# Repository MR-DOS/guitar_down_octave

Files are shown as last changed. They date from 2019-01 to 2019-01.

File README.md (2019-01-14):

# guitar_down_octave
----
## Description
This is an analog guitar effect which works as octave-down effect. Contrary to all available analog octave-down effect (let me know if you find one!), it produces undistorted sinewave (when supplied with pure sinewave on input). There is no PLL, no oscillator

----
## Overview
So, you may want to know how it works. A long time ago, I was experimenting with octave-up effects. Recently, I thought that the principle of octave-up effects can be turned inside-out and a bit expanded to make an octave-down effect. The way most octave-up effects work (the good ones, simple ones only rectify the input waveform which is horrible) is as follows:

sin^2(x)=\frac{sin(2x)}{2}+\frac{1}{2}

If this function is inverted, you get:

\sqrt{\frac{sin(x)}{2}+\frac{1}{2}}=|sin(\frac{x}{2})|

However, this is not enough to turn sinewave into sinewave of half frequency. You need to remove the absolute value and this is where the analog mojo kicks in.
If you want more insight, look in the presentation where simulated waveforms can be found. If you are more curious, look into the schematics or simulation.

----
## Explanation of function
To sum it up, the circuit does the following: detect input amplitude and shift the input signal in such a way that the sinewave has its minimum at precisely 0 Vdc, find a square root of the shifted signal and normalize its amplitude so that input and output amplitudes are equal, then invert the signal at points where it gets closest to zero.

### 90deg phasing circuit
In order to detect extremes, you need to detect zero crossing of a derivation of the input signal. Initially, derivator was used, but it had several issues, most importantly its sensitivity was increasing with frequency whereas I needed quite the opposite, because the circuit needs to be most sensitive in the range of tens of Hz to several hundreds of Hz. The sensitivity also should decrease with rising frequency to make the phasing circuit more immune to harmonics (because signal from guitar is going to be flooded with harmonics). So a double integrator was used - one for the phasing circuit, one as DC servo. However, this circuit has a nasty peak at 32 Hz, so it had to be compensated with a Twin-T notch filter right on the input of the whole effect. It maintains proper 90deg +- 0.25deg phase from about 60 Hz and up. There is an additional RC T-network to accelerate convergence to 90deg at low frequencies, which allows for more gain in the integrator by using shorter time constant. It should work even with harmonic-rich signals, however the harmonics must be in phase (and not antiphase) with the fundamental frequency, otherwise an analysis of what will happen is nontrivial.

Schematics of the input circuit with the notch filter and the phasing circuit:
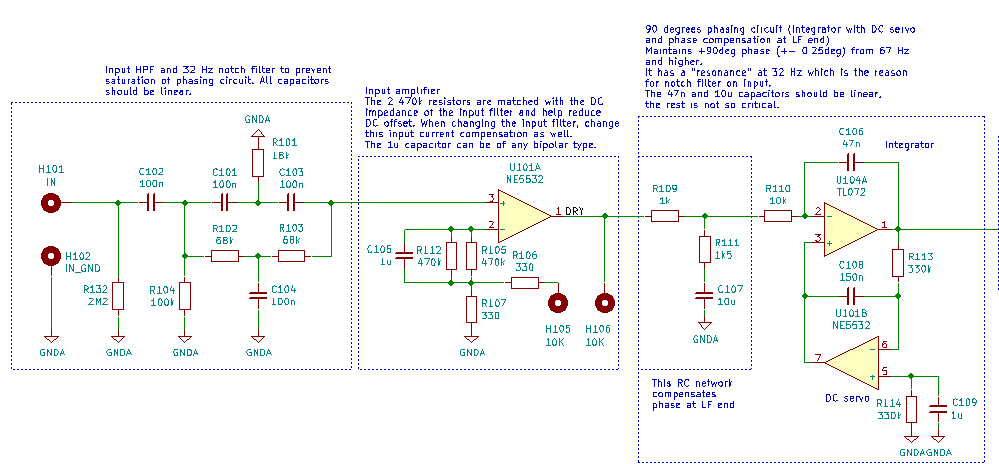
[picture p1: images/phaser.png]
Schematics of the input circuit with the notch filter and the phasing circuit


Green sine is the input waveform, blue is the 90deg shifted sine, red is output of the comparator:
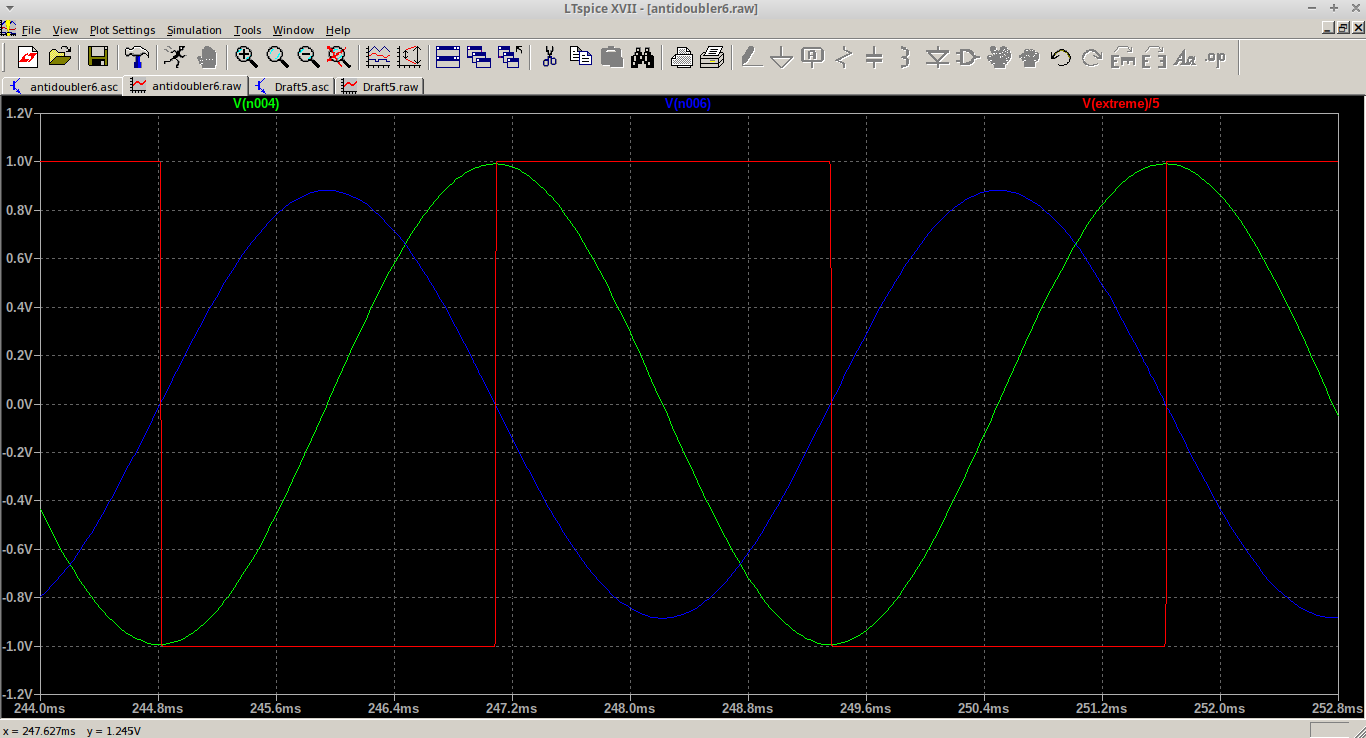
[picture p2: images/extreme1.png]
Green sine is the input waveform, blue is the 90deg shifted sine, red is output of the comparator


### Synchronous peak detector
There is a synchronous peak detector which uses 2 track-and-hold amplifiers (historical LF398). One of them tracks the input signal while the second one holds a peak value. Each time the input waveform goes through one of its extremes, their tasks are switched. At the same time, an analog switch selects the one which holds the peak value. This way, you get a fairly precise DC value representing the amplitude which is updated after each cycle of the sinewave. This was needed because regular peak detectors were too slow to react fast enough to dynamics of playing a guitar while being too fast to hold their value during the whole cycle of sinewave, so they would cause a lot of distortion and bad dynamics.
This part and the phasing circuit proved to be crucial for proper operation of the whole effect.

Green sine is the input waveform, blue and light blue waveforms are outputs of the track-and-hold amplifiers:
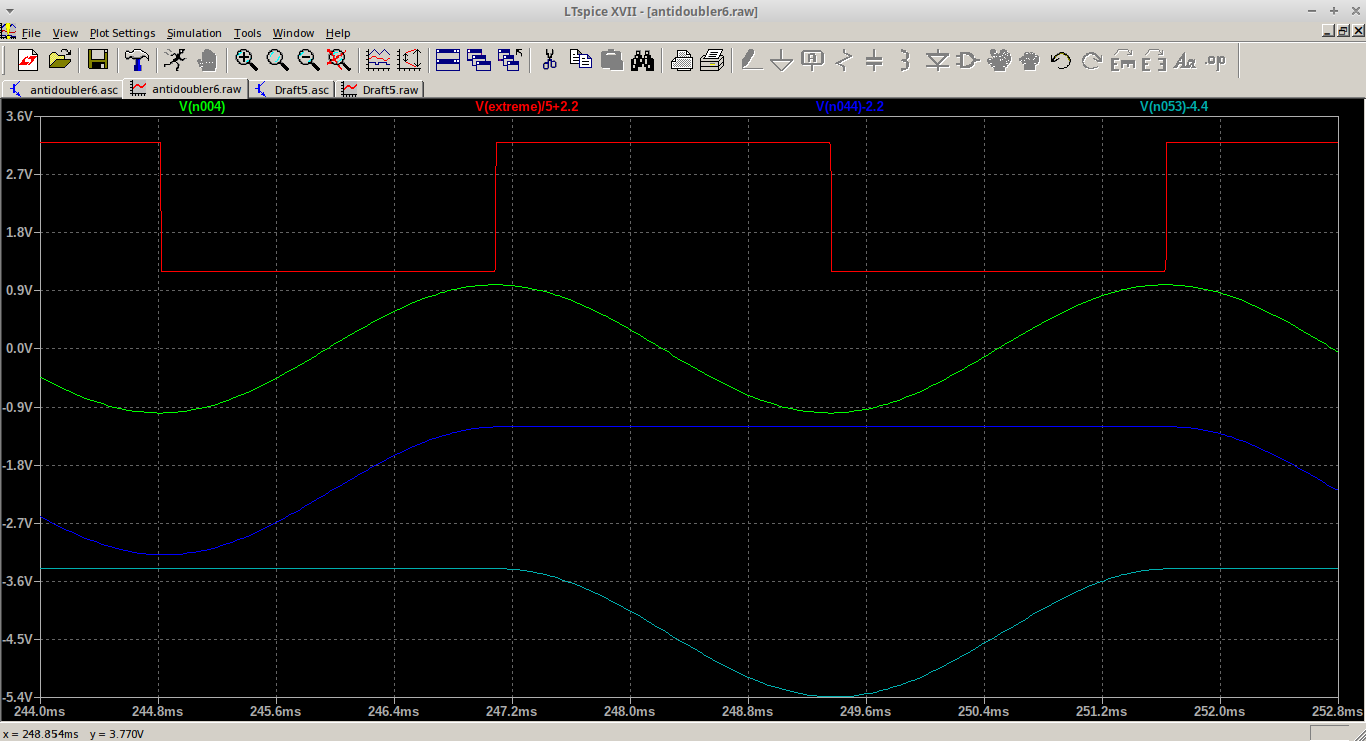
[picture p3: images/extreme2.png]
Green sine is the input waveform, blue and light blue waveforms are outputs of the track-and-hold amplifiers


### Square root finder
The square root finder is quite simple - it uses opamps and diodes to calculate the logarithm of the DC shifted signal, then divide by two (simple resistor divider) and exponentiate. This computes the square root even with proper sign. The only problem is very low speed of this circuit when crossing zero (which is why it never should cross the zero), because it momentarily goes open-loop and has to cross about 1.3 V rapidly.

Square-root-finder schematics:
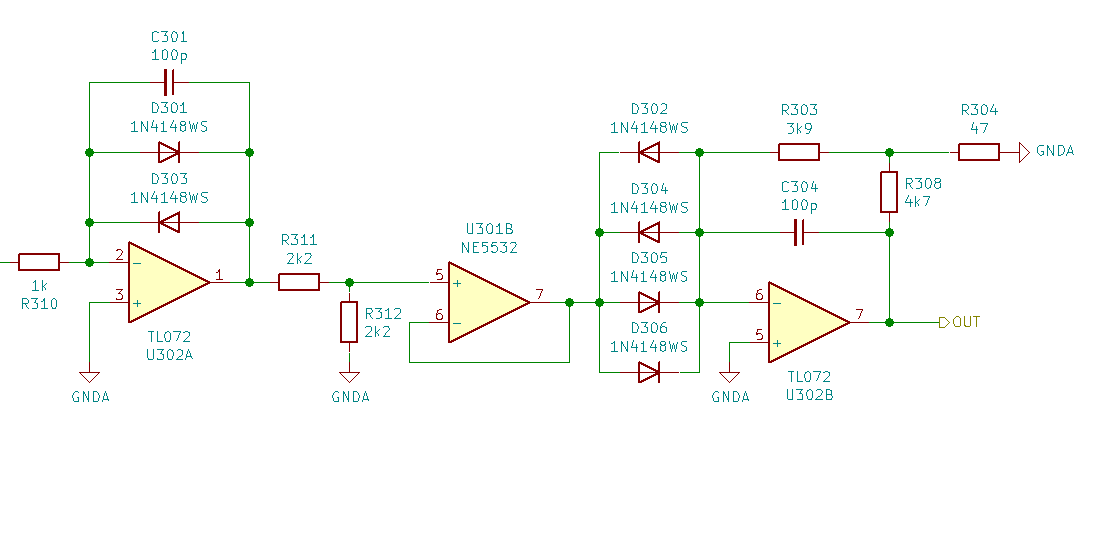
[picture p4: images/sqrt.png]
Square root-finder


Waveforms in the square-root-finder:
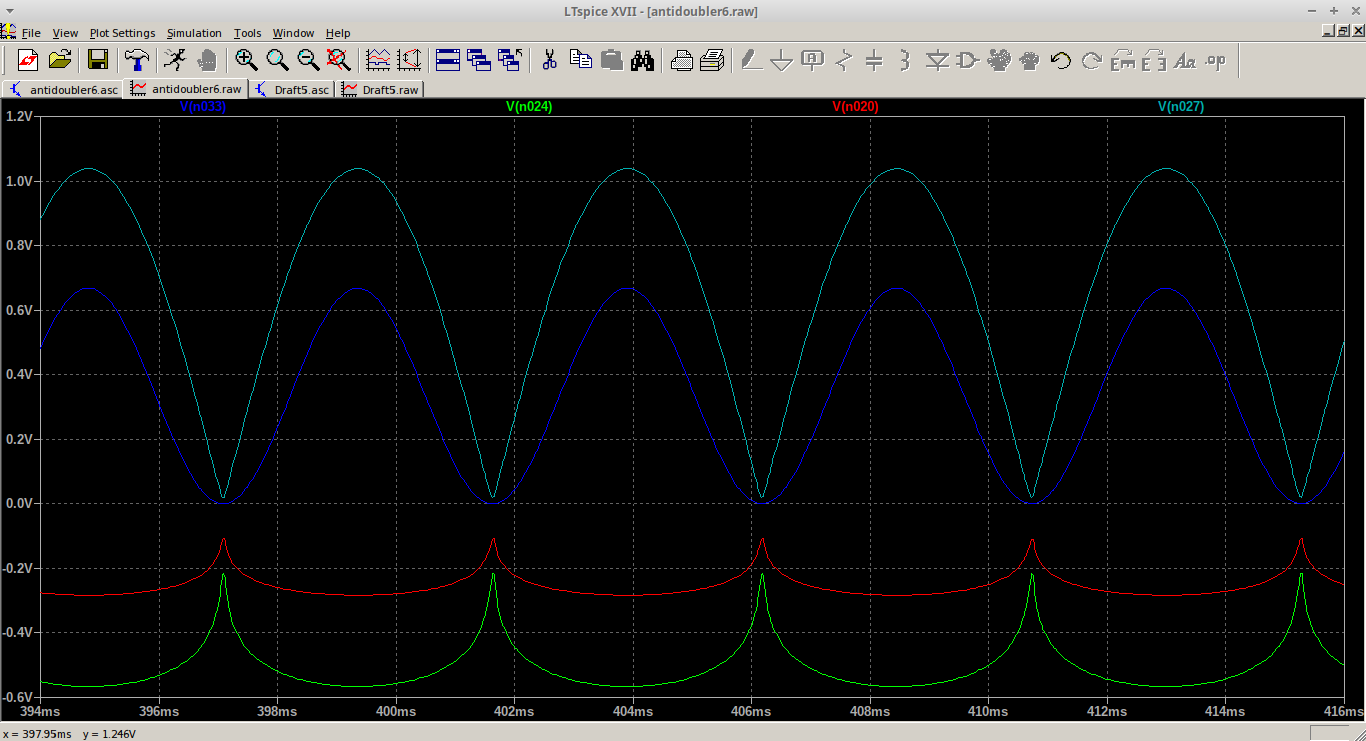
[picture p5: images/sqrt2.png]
Waveforms in the square-root-finder


### Synchronous inverter
To get rid of the absolute value, there is a synchronous inverter which inverts every second halfperiod of the sinewave. This uses the phasing circuit and 74HC74 to generate half frequency square wave which drives an analog switch which selects either positive or negative halfperiod of the sinewave. There is a simple RC filter to suppress crossover distortion.

Green and light blue line are the noninverted and inverted value, dark blue is the combined waveform:
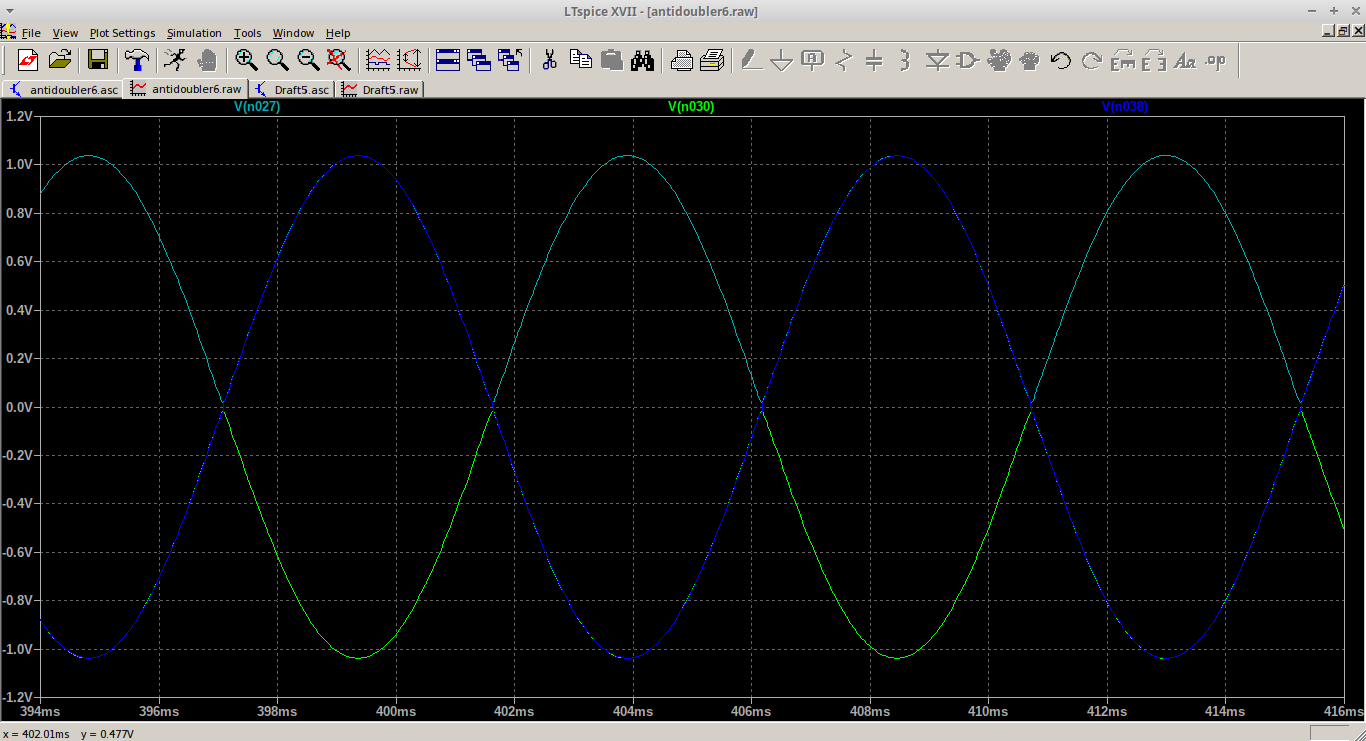
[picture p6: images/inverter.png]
Green and light blue line are the noninverted and inverted value, dark blue is the combined waveform


### AGC
To compensate for amplitude error due to the square-root, there is an AGC which uses Gilbert cells. Each square-root-finder is preceded by the Gilbert cell (there are 2), one has the sine wave as input, the second one gets the DC value of amplitude. The AGC tries to get the input and output amplitude the same.

Gilbert cell used as controlled amplifier:
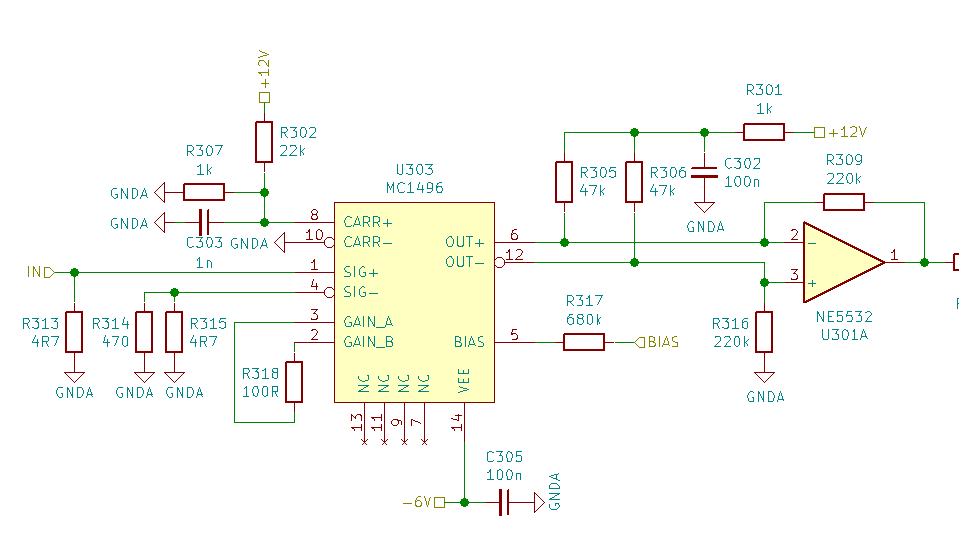
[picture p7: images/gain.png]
Gilbert cell used as controlled amplifier


Feedback used to compute the AGC value:
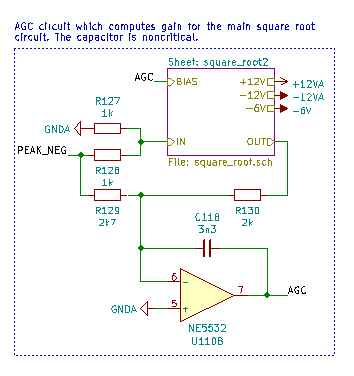
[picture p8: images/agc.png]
Feedback used to compute the AGC value


----
### Performance
Performance at 110 Hz, 1Vpk-pk:
The largest harmonic is the 3rd with -62.3 dBc, the THD is about 0.43% or 2.97% depending on how you define the THD. For a nonlinear guitar effect, it is probably satisfactory.

Image of FFT in simulation:
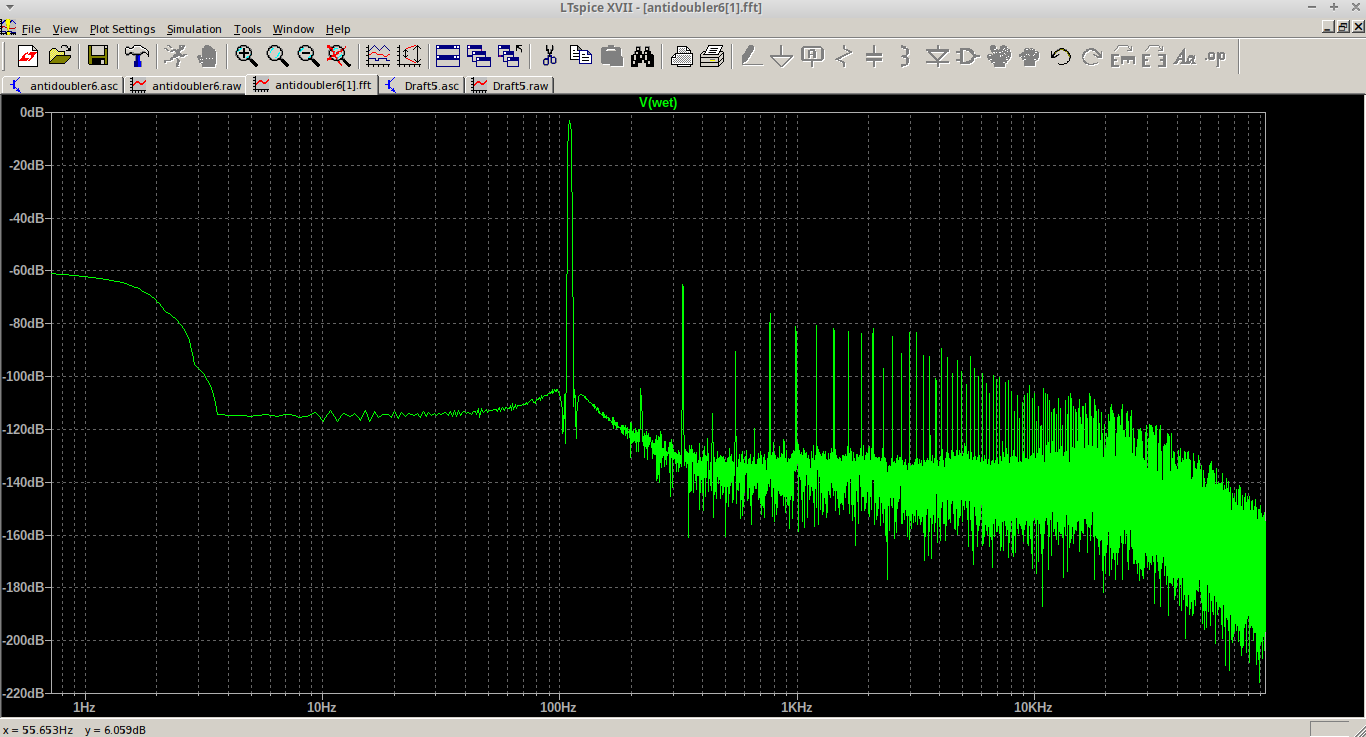
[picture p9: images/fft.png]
Image of FFT in simulation


----
## Images of the board
Top view:
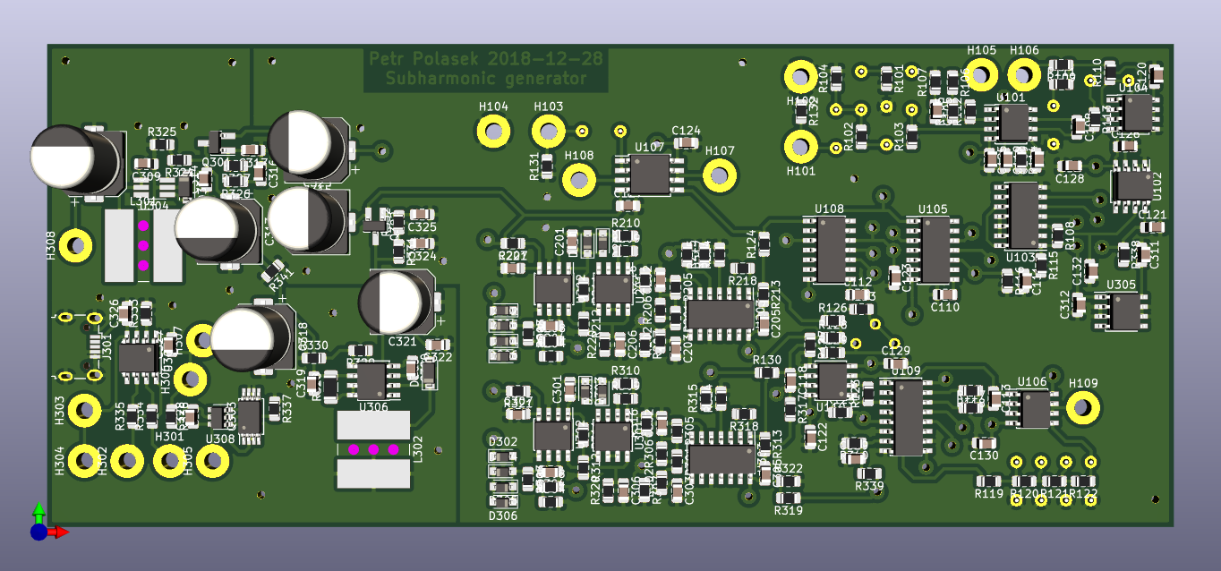
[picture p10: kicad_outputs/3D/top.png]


Bottom view:
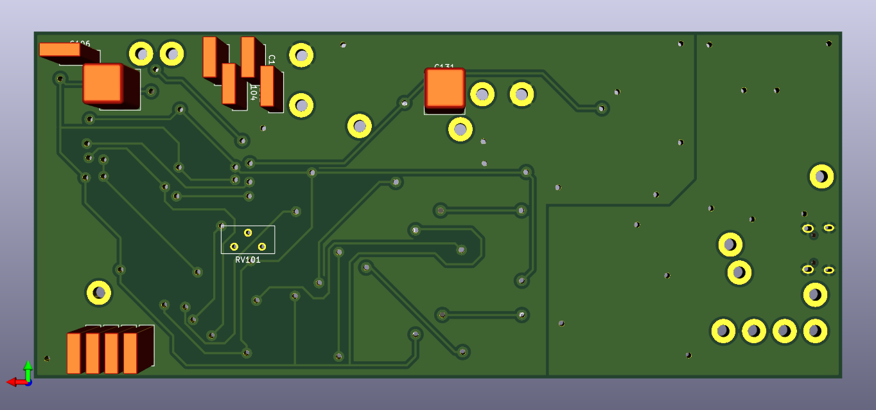
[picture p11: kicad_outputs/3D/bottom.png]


Top view, drilled and with vias in place:
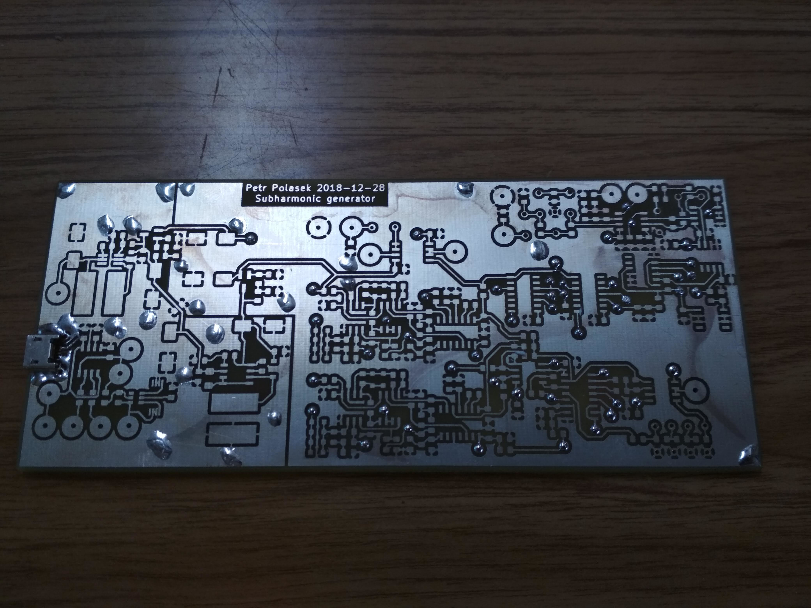
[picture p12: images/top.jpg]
Top view, drilled and with vias in place


Bottom view, drilled and with vias in place:
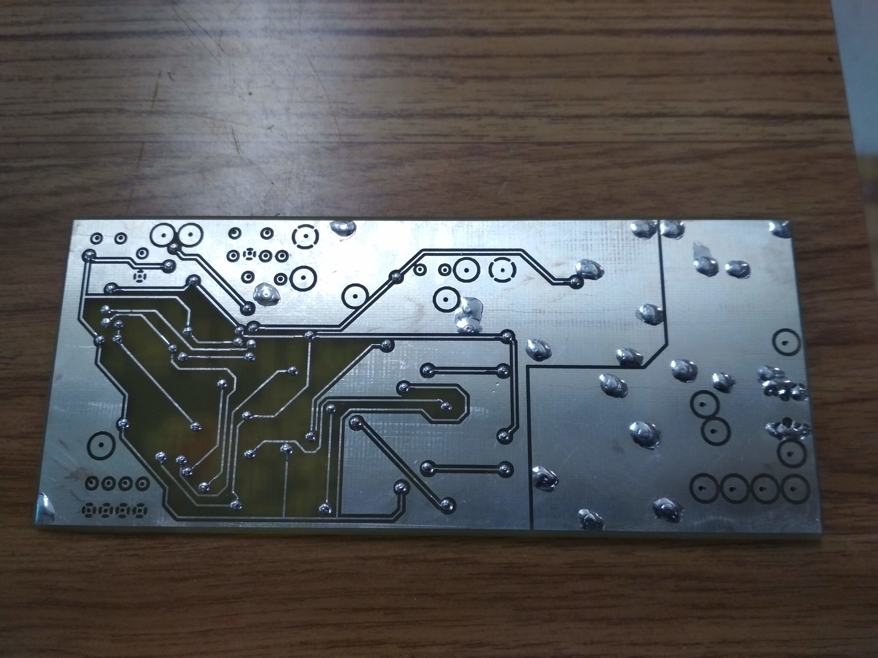
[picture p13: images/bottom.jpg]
Bottom view, drilled and with vias in place


Assembled board:
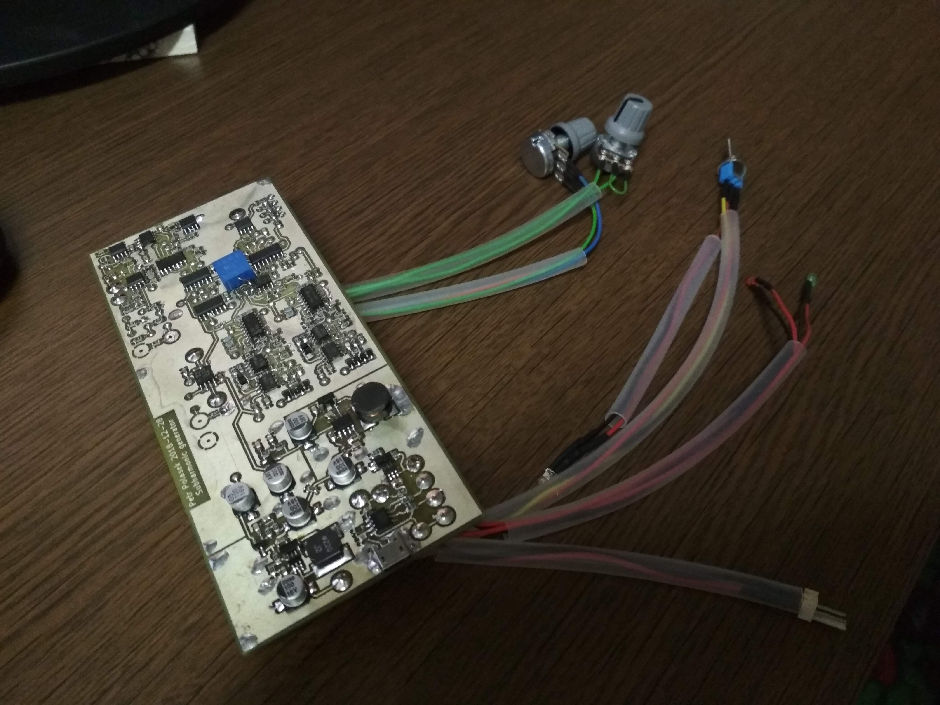
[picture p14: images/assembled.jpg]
Assembled board


----
## Known bugs
The -15 V switching power supply is a piece of shit. I will never EVER use MC34063, at least for negative power supply. The modern positive switching power supply is OK, it draws only tens of mA. The MC34063 draws one or two orders of magnitude larger current. Maybe it could be replaced by charge pump taken from the positive switching power supply - this means replacing the whole negative power supply by 2 diodes and 1 capacitor.

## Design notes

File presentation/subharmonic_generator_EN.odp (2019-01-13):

## Subharmonic generator B2M34IAS

Petr Polášek

3.1.2018

## 90° phasing circuit - schematic

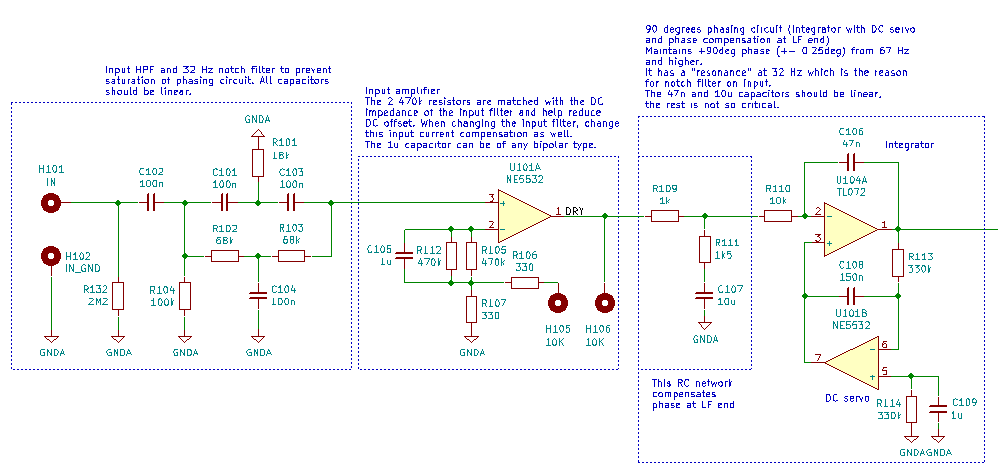
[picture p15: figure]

## 90° phasing circuit - schematic

## 90° phasing circuit - characteristics

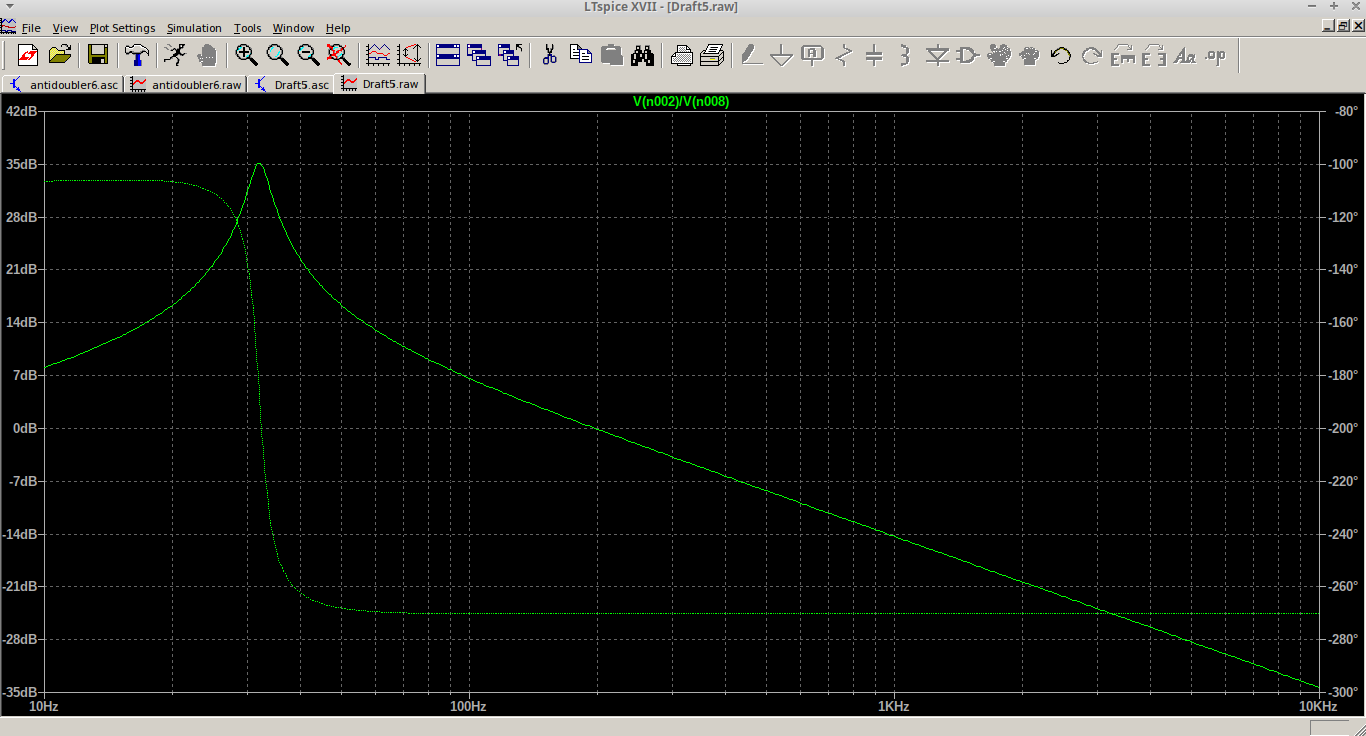
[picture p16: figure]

## 90° phasing circuit - schematic

## 90° phasing circuit – notch filter

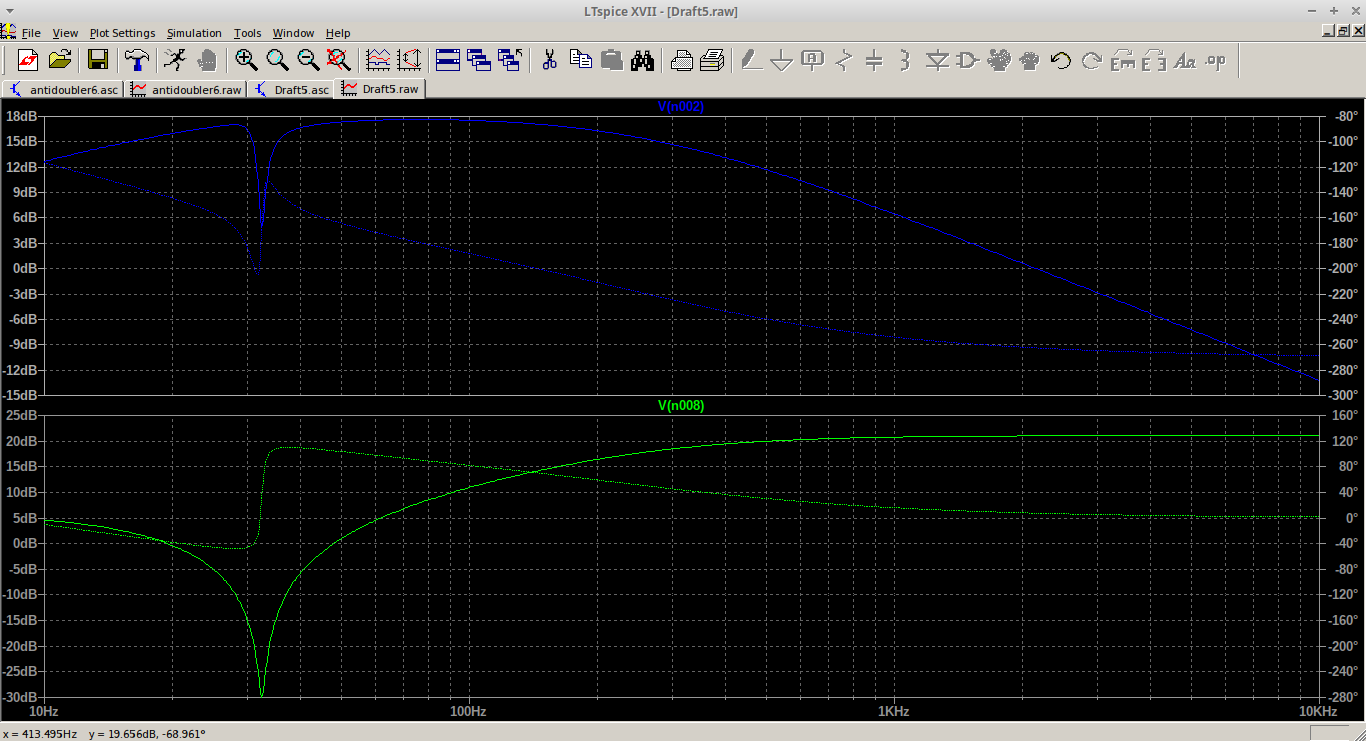
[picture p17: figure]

## 90° phasing circuit – phase accuracy

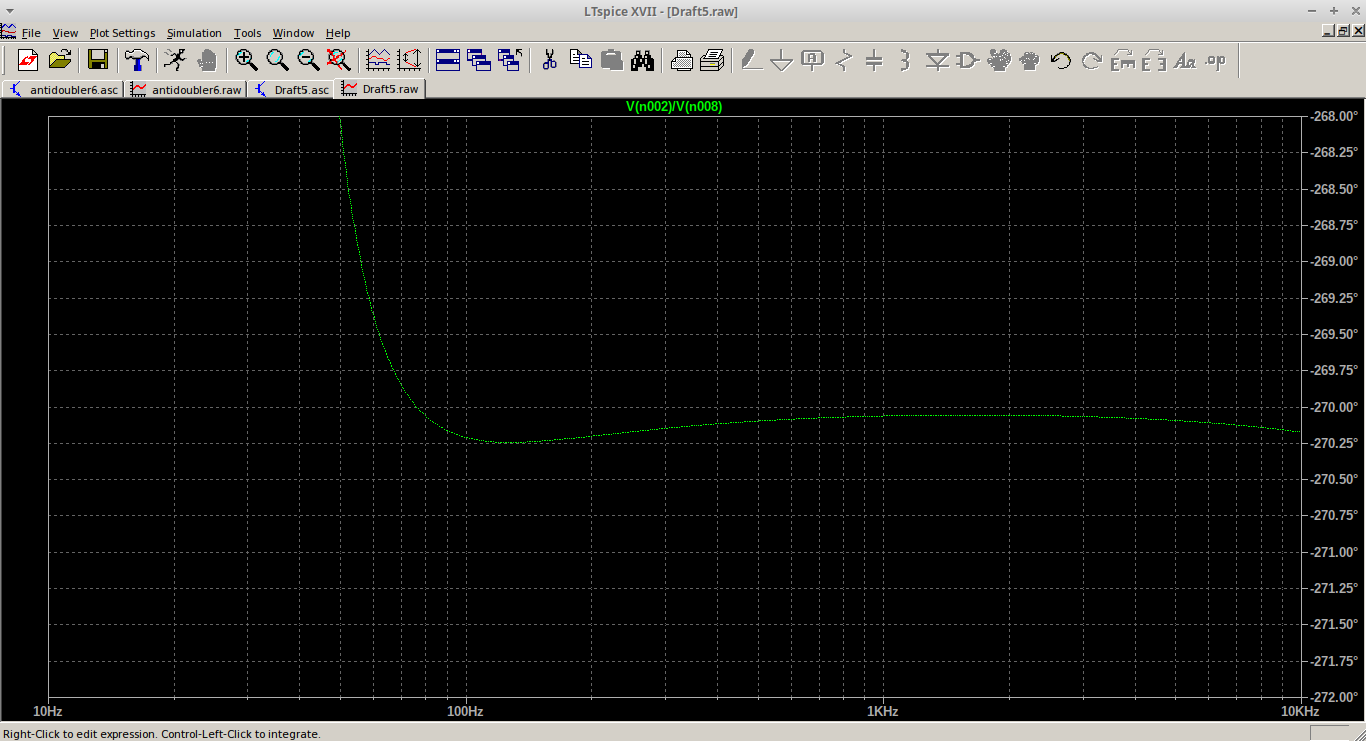
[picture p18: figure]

## Extreme detector - schematic

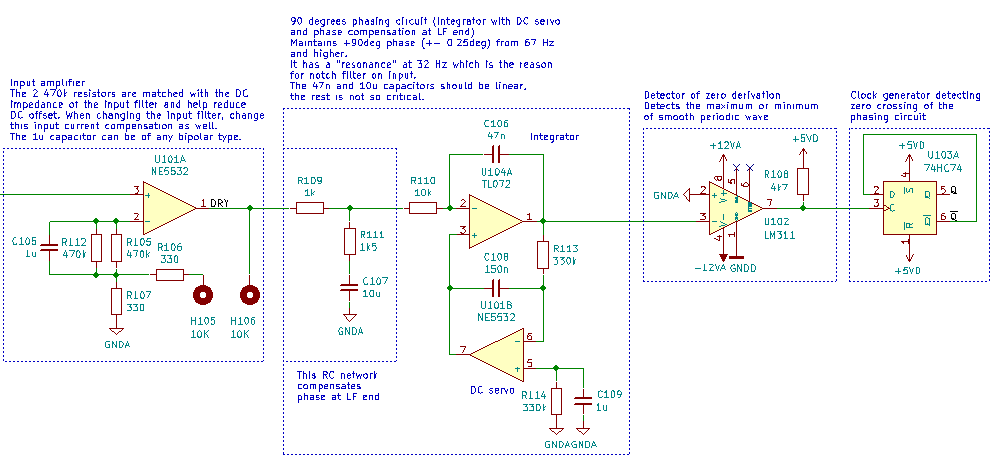
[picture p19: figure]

## Extreme detector - waveforms


## Synchronous extreme detectors

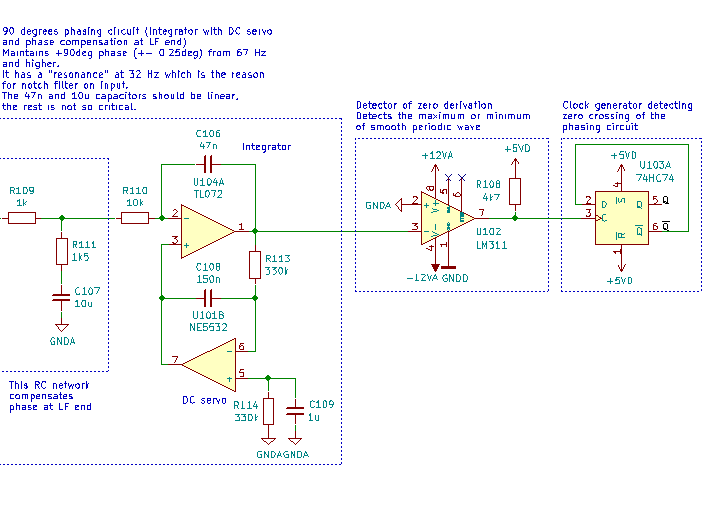
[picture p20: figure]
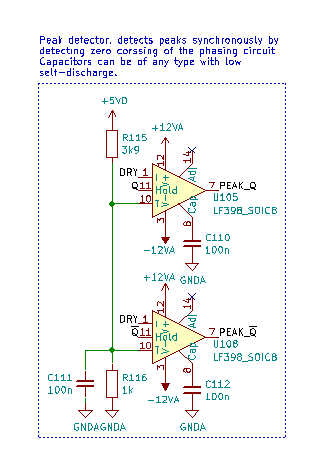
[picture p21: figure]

## Synchronous extreme detectors


## Synchronous extreme detectors

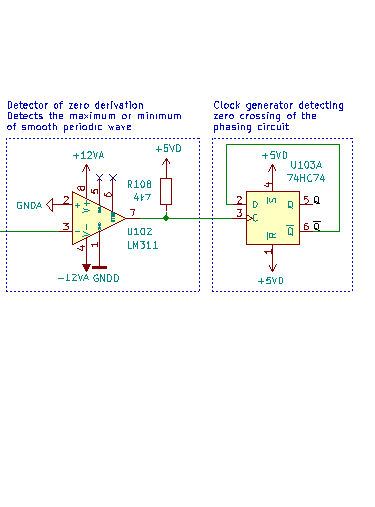
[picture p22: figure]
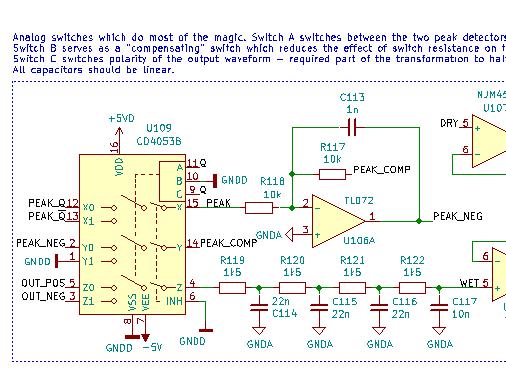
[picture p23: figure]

## Synchronous extreme detectors

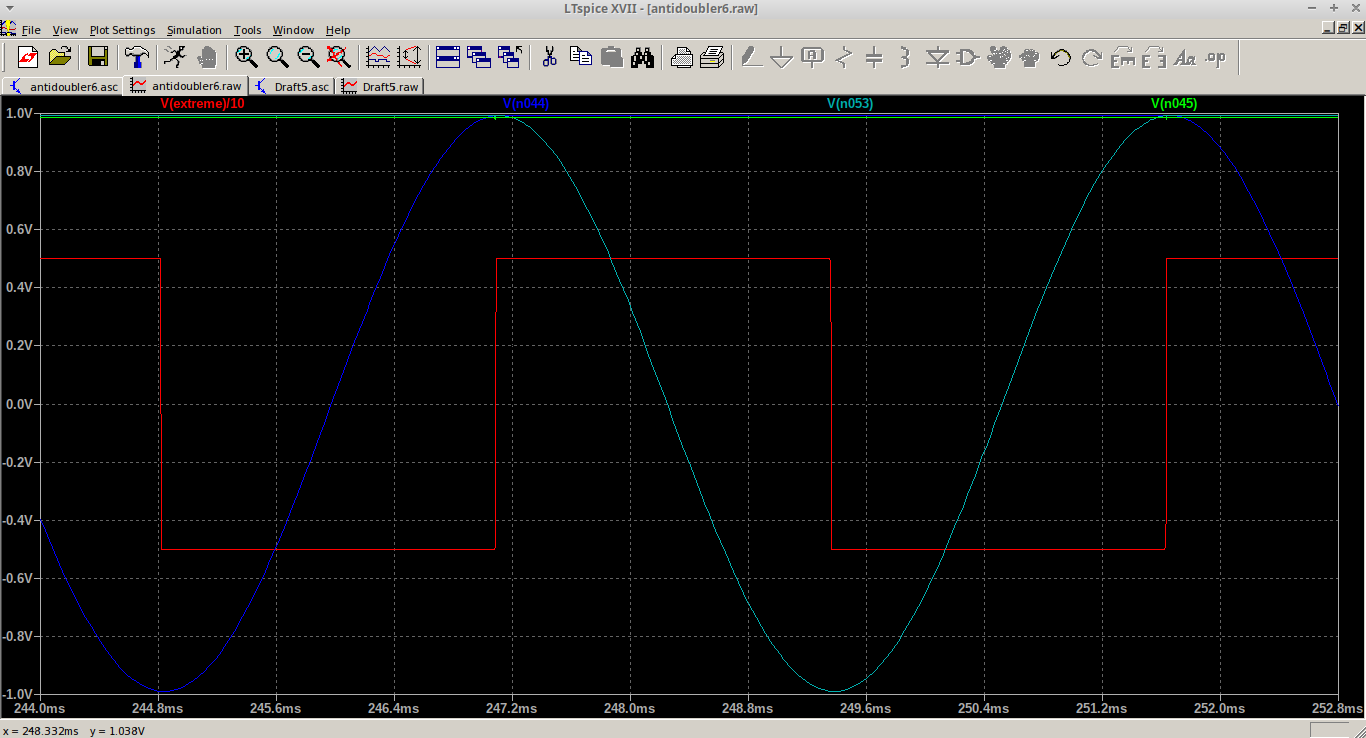
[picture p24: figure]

## Synchronous extreme detector accuracy

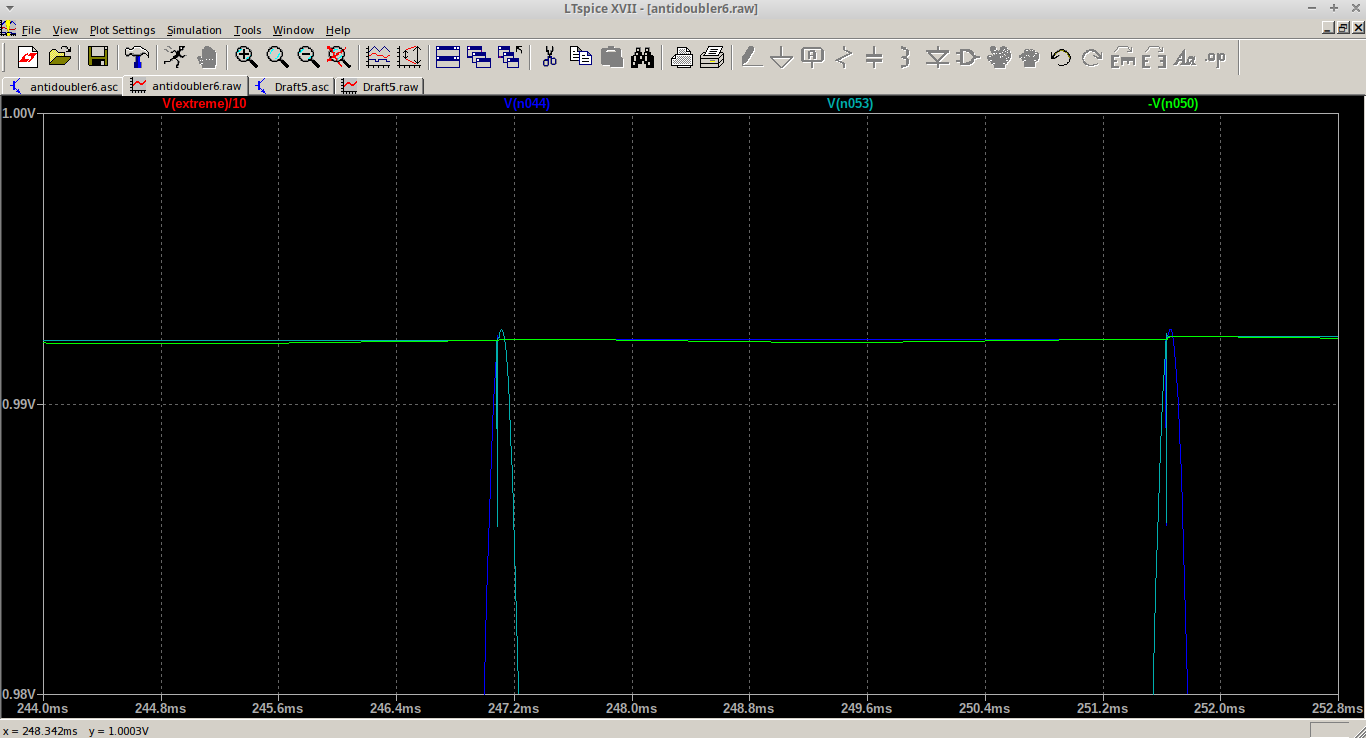
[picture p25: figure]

## Synchronous extreme detectors

0.35 mV @ 1V
0.03% error

## Square root finder - schematic

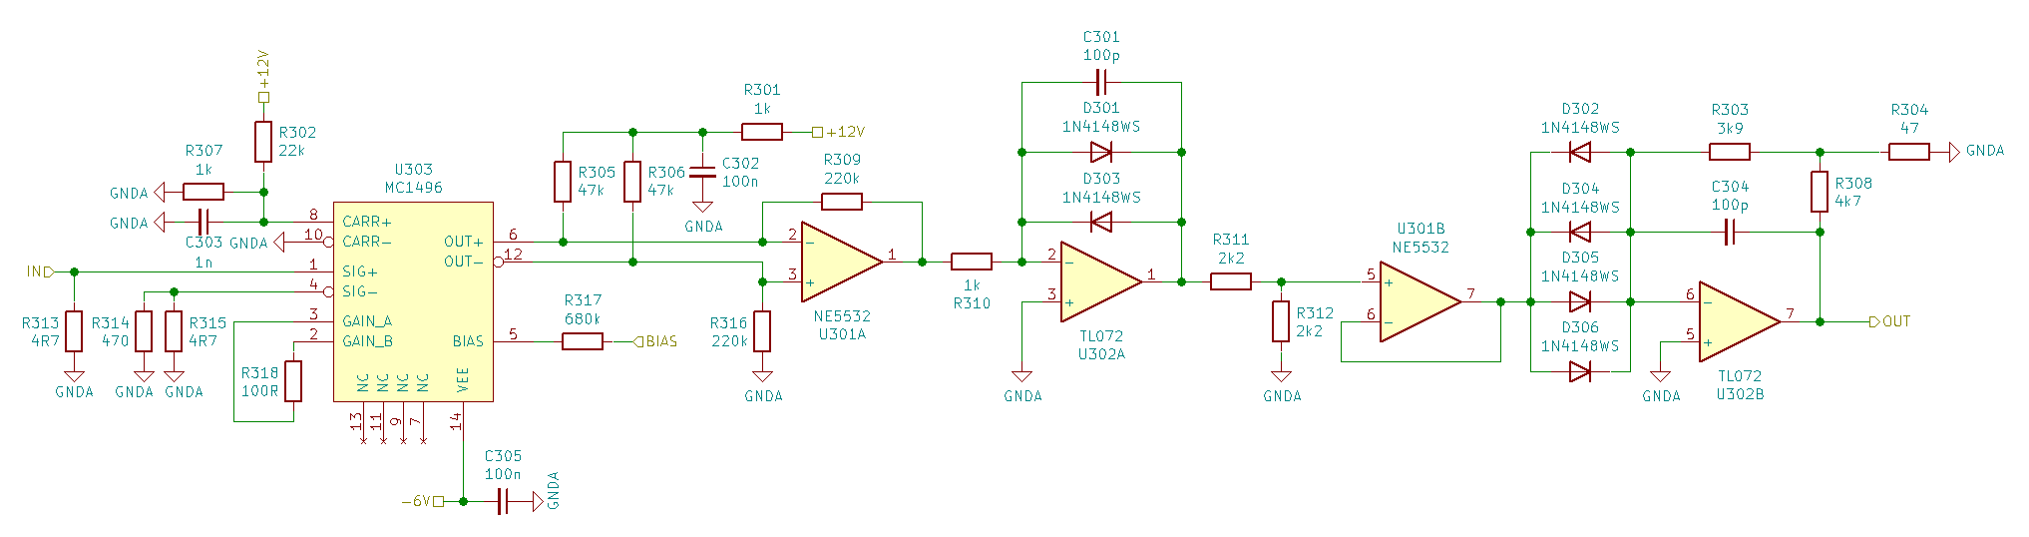
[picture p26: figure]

## Square root finder – gain control

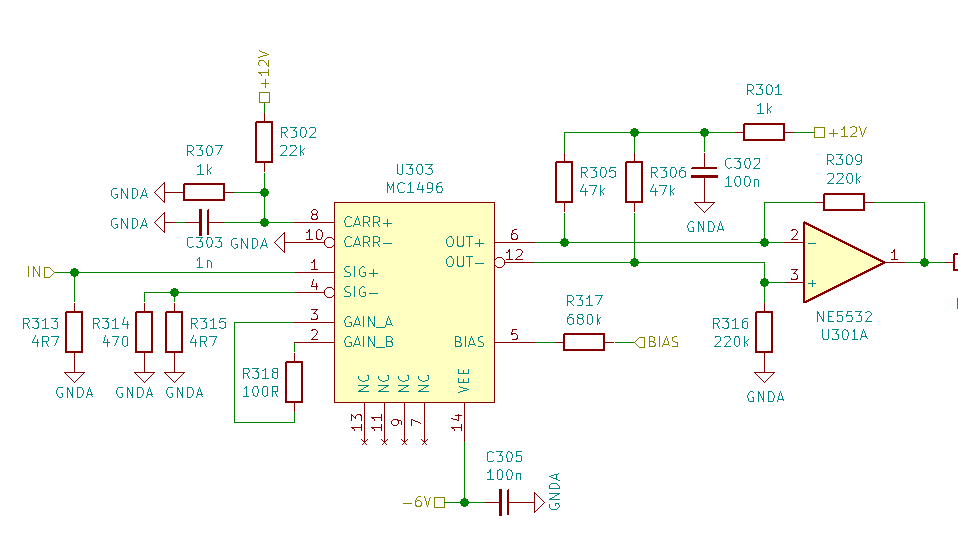
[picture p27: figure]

## Square root finder – square root cell

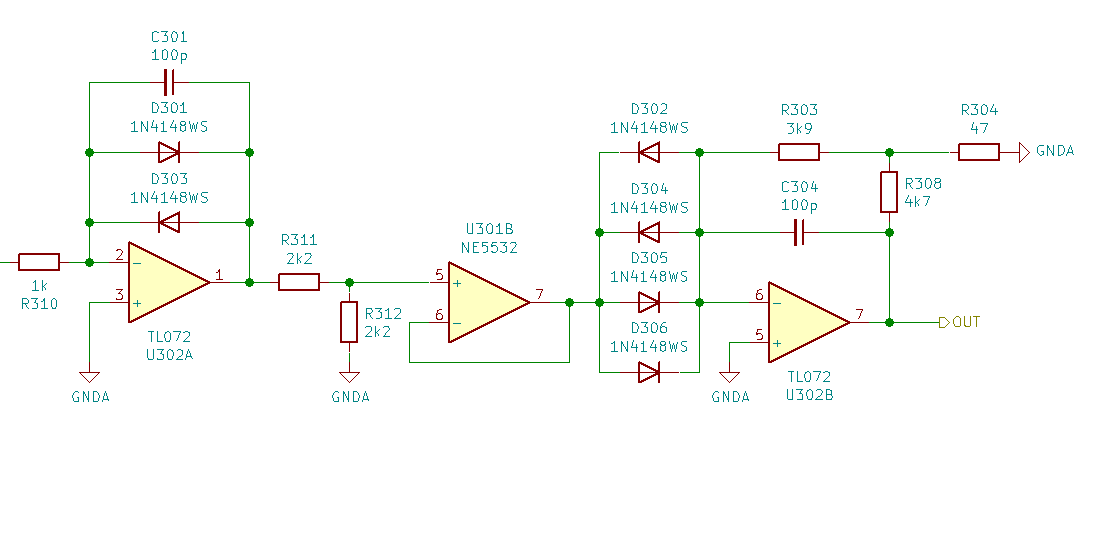
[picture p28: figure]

## Square root finder - waveforms


## Square root finder – AGC feedback

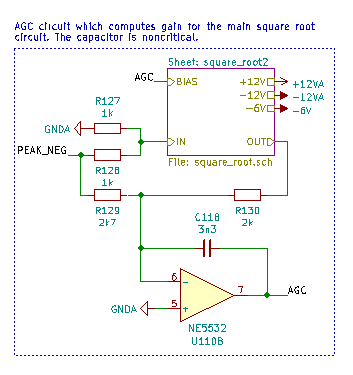
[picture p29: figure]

## Polarity inverter - schematics

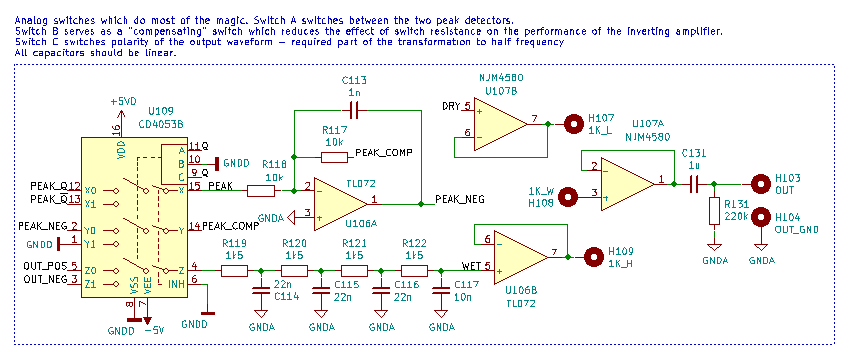
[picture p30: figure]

## Polarity inverter - waveforms


## Polarity inverter - schematics

## Polarity inverter – crossover distortion

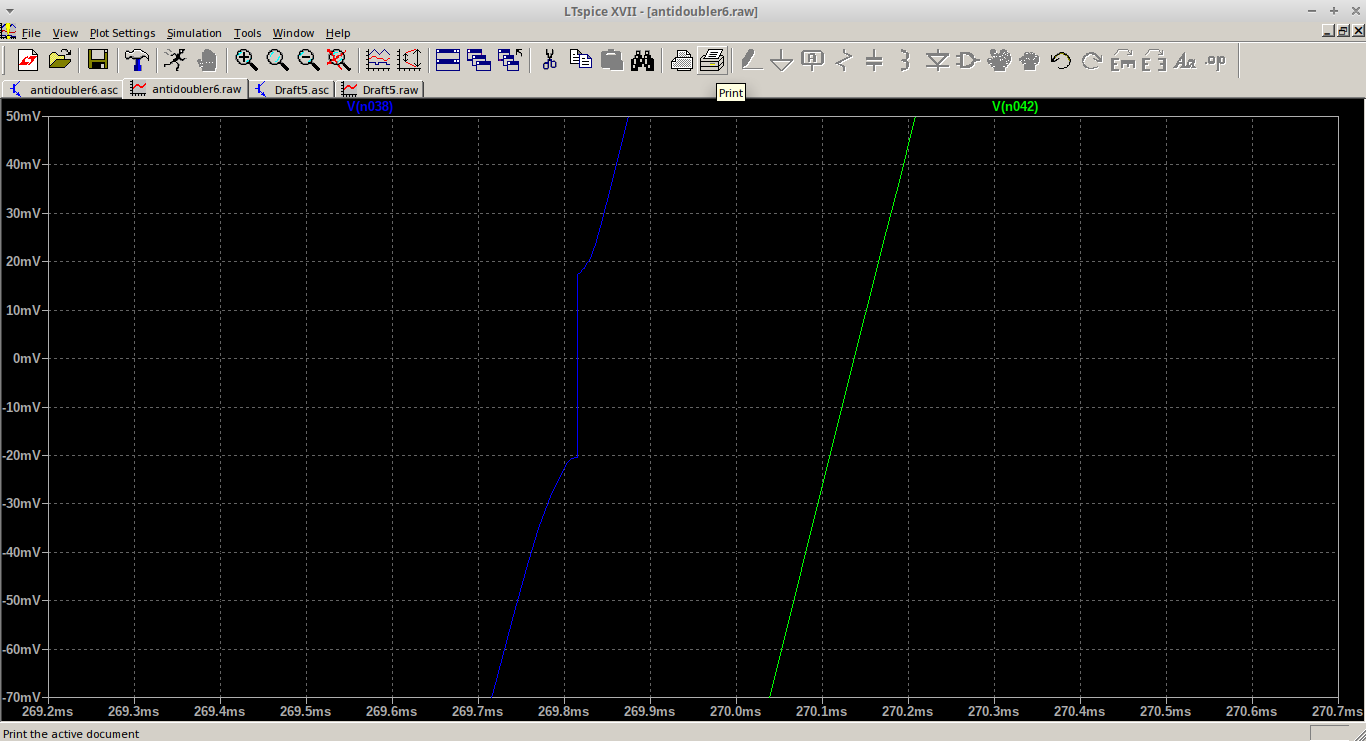
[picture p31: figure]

## Output signal FFT


## Output signal FFT - magnified

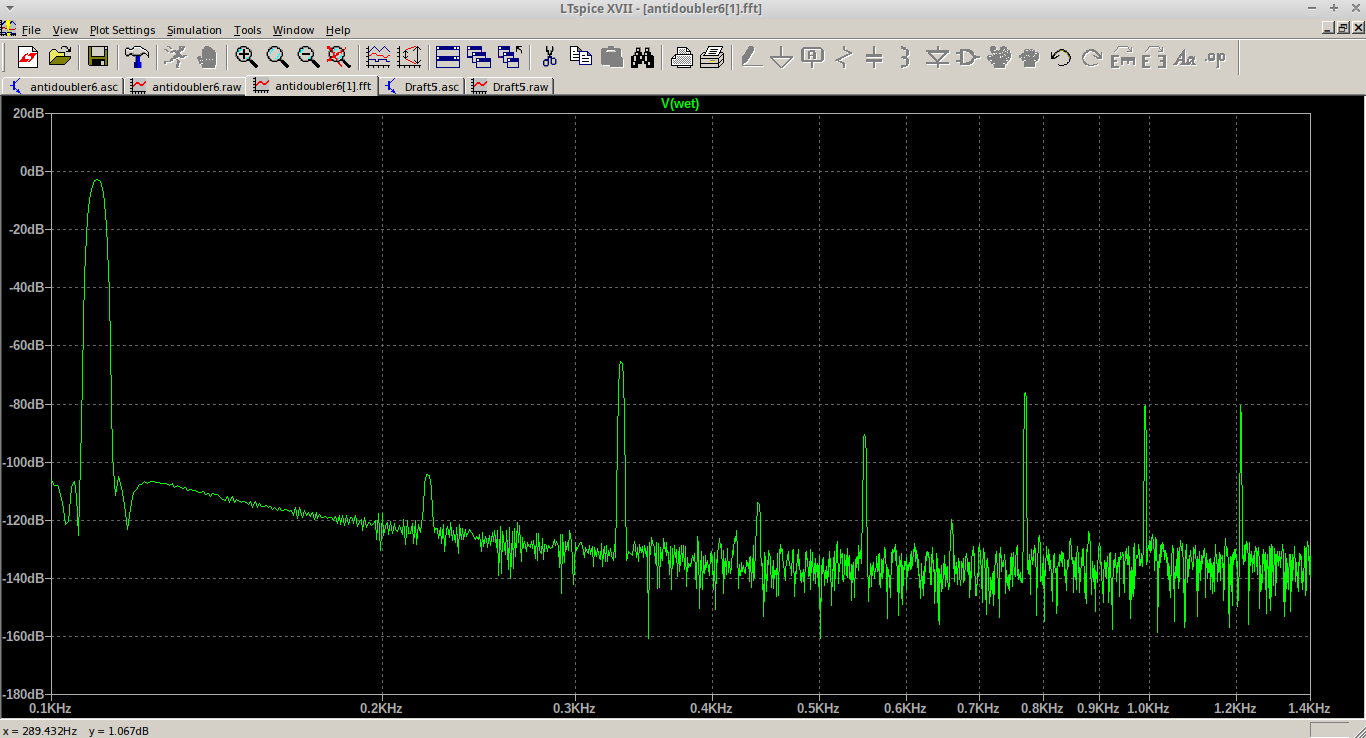
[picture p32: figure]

-62.3 dBc @ 3rd harmonic

THDR = 0.43 %

THDF = 2.97 %

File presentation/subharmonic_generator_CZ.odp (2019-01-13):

## Subharmonický generátor B2M34IAS

Petr Polášek

3.1.2018

## Fázovací 90° článek - zapojení


## Fázovací 90° článek - zapojení

## Fázovací 90° článek - přenos


## Fázovací 90° článek - zapojení

## Fázovací 90° článek – celkový přenos


## Fázovací 90° článek – přesnost fáze


## Detektor průchodu extrémem - zapojení


## Detektor průchodu extrémem - průběh


## Synchronní detektory maxima - zapojení


## Synchronní detektory maxima - průběhy


## Synchronní detektory maxima - zapojení


## Synchronní detektory maxima - průběhy


## Synchronní detektory maxima - průběhy


## Synchronní detektory maxima - průběhy

0.35 mV @ 1V
0.03% chyba

## Odmocňovací buňka - zapojení


## Odmocňovací buňka – řízení zisku


## Odmocňovací buňka - odmocňovačka


## Odmocňovací buňka - odmocňovačka


## Odmocňovací buňka – zpětná vazba


## Řízená inverze signálu - zapojení


## Řízená inverze signálu - průběhy


## Řízená inverze signálu - zapojení

## Řízená inverze signálu - offset


## FFT výstupního signálu


## FFT výstupního signálu - příblížení


-62.3 dBc

THDR = 0.43 %

THDF = 2.97 %

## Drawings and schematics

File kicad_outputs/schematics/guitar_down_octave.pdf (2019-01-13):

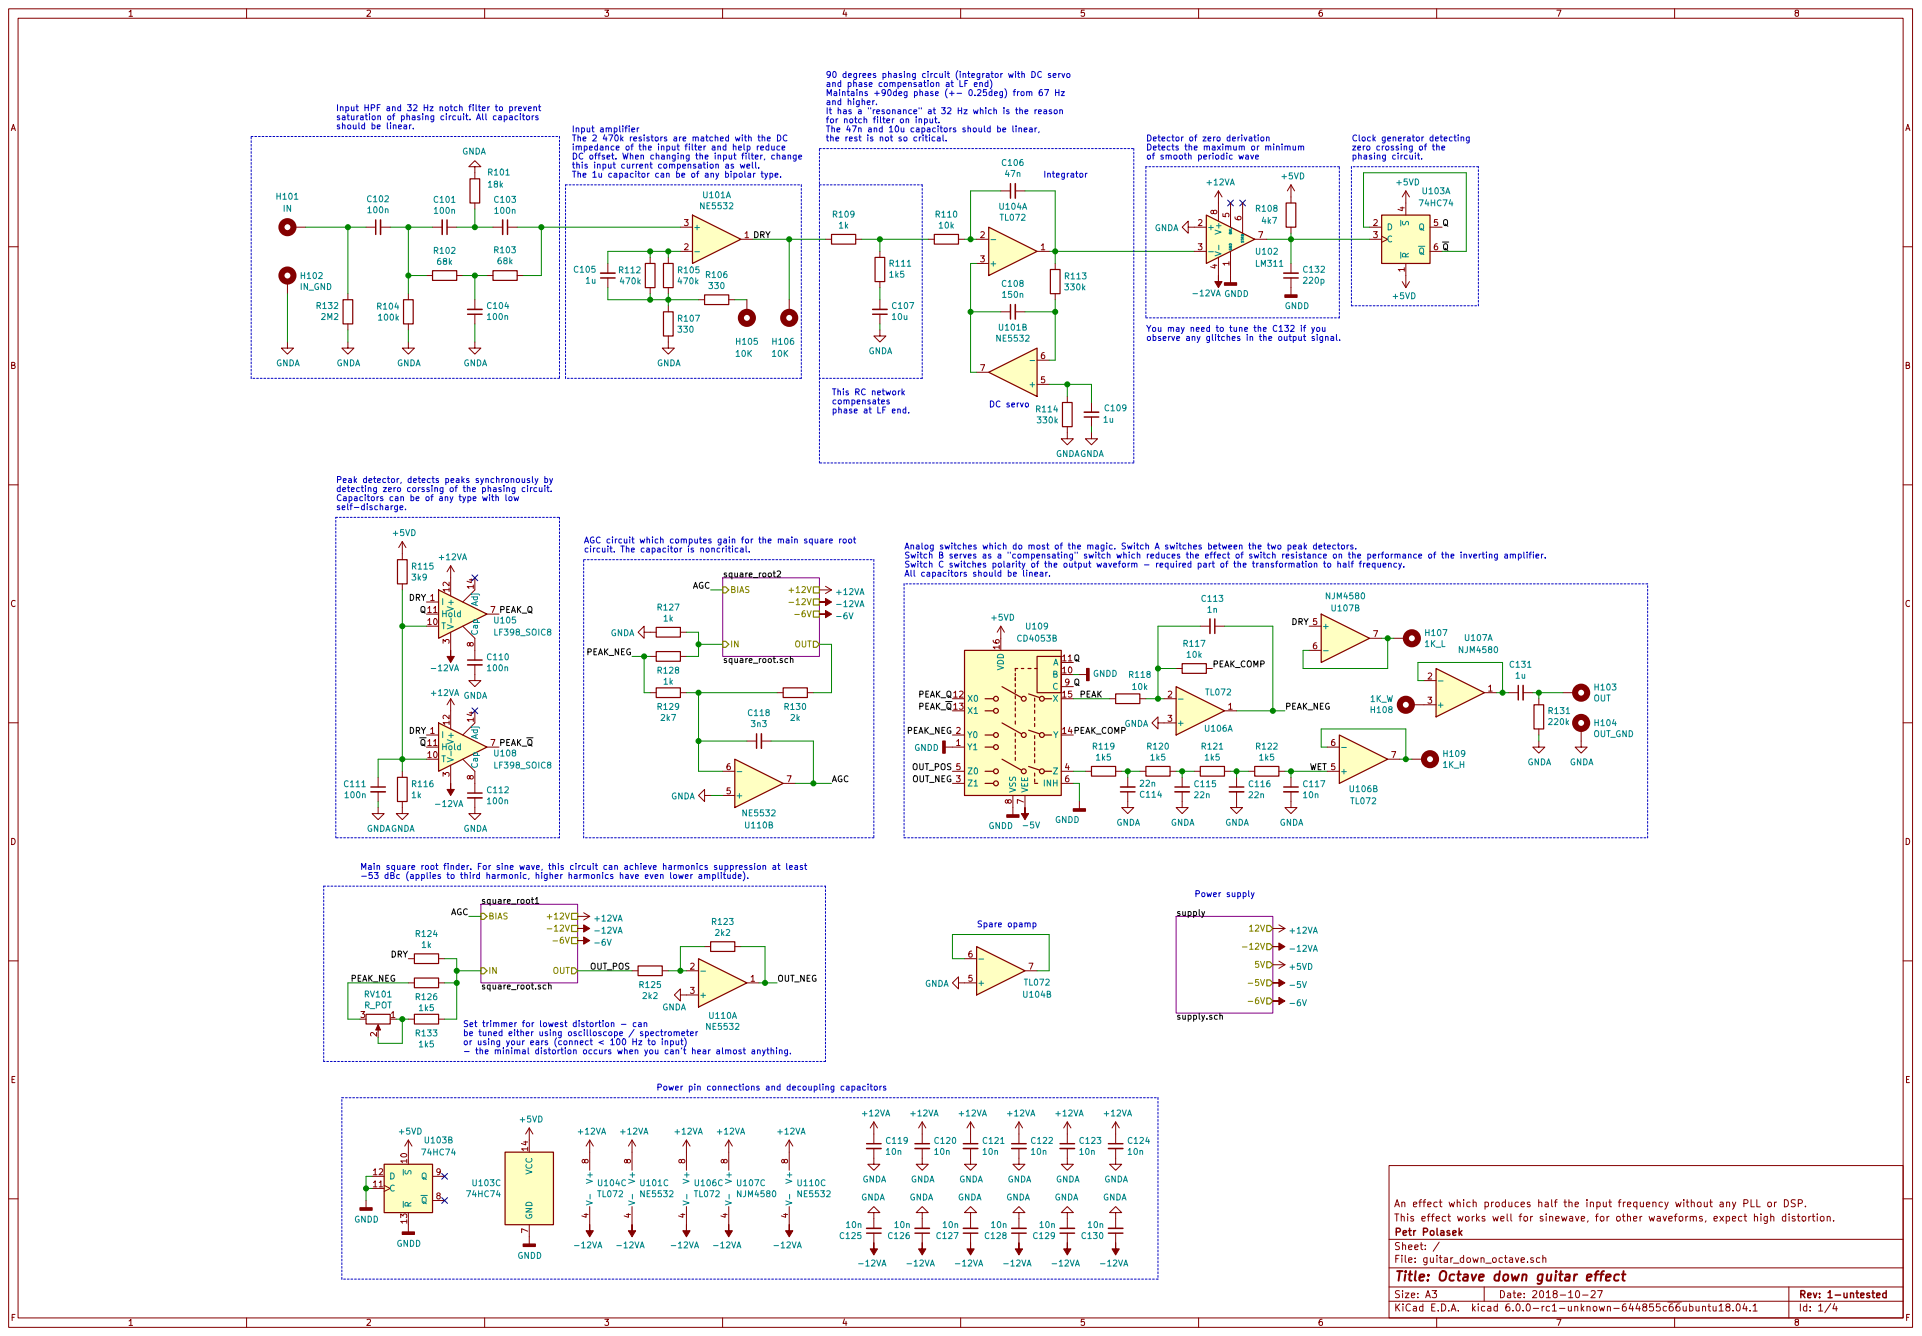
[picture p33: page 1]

and phase compensation at LF end)
Maintains +90deg phase (+- 0.25deg) from 67 Hz
and higher.
It has a "resonance" at 32 Hz which is the reason
for notch filter on input.
The 47n and 10u capacitors should be linear,
Integrator DC servo

Input HPF and 32 Hz notch filter to prevent
saturation of phasing circuit. All capacitors

Input amplifier The 2 470k resistors are matched with the DC
impedance of the input filter and help reduce
DC offset. When changing the input filter, change
this input current compensation as well.

of smooth periodic wave

+5VD +12VA - 3 V- 4 BAL 5 STRB 6 LM311 GNDA

You may need to tune the C132 if you
observe any glitches in the output signal.

This RC network
compensates phase at LF end.

Peak detector, detects peaks synchronously by
detecting zero corssing of the phasing circuit.
Capacitors can be of any type with low

AGC circuit which computes gain for the main square root
circuit. The capacitor is noncritical.

Switch B serves as a "compensating" switch which reduces the effect of switch resistance on the performance of the inverting amplifier.
Switch C switches polarity of the output waveform - required part of the transformation to half frequency.

Main square root finder. For sine wave, this circuit can achieve harmonics suppression at least

or using your ears (connect < 100 Hz to input)
- the minimal distortion occurs when you can't hear almost anything.

Power pin connections and decoupling capacitors

An effect which produces half the input frequency without any PLL or DSP.
File: guitar_down_octave.sch Sheet: / Petr Polasek This effect works well for sinewave, for other waveforms, expect high distortion.

Id: 1/4 Title: Octave down guitar effect

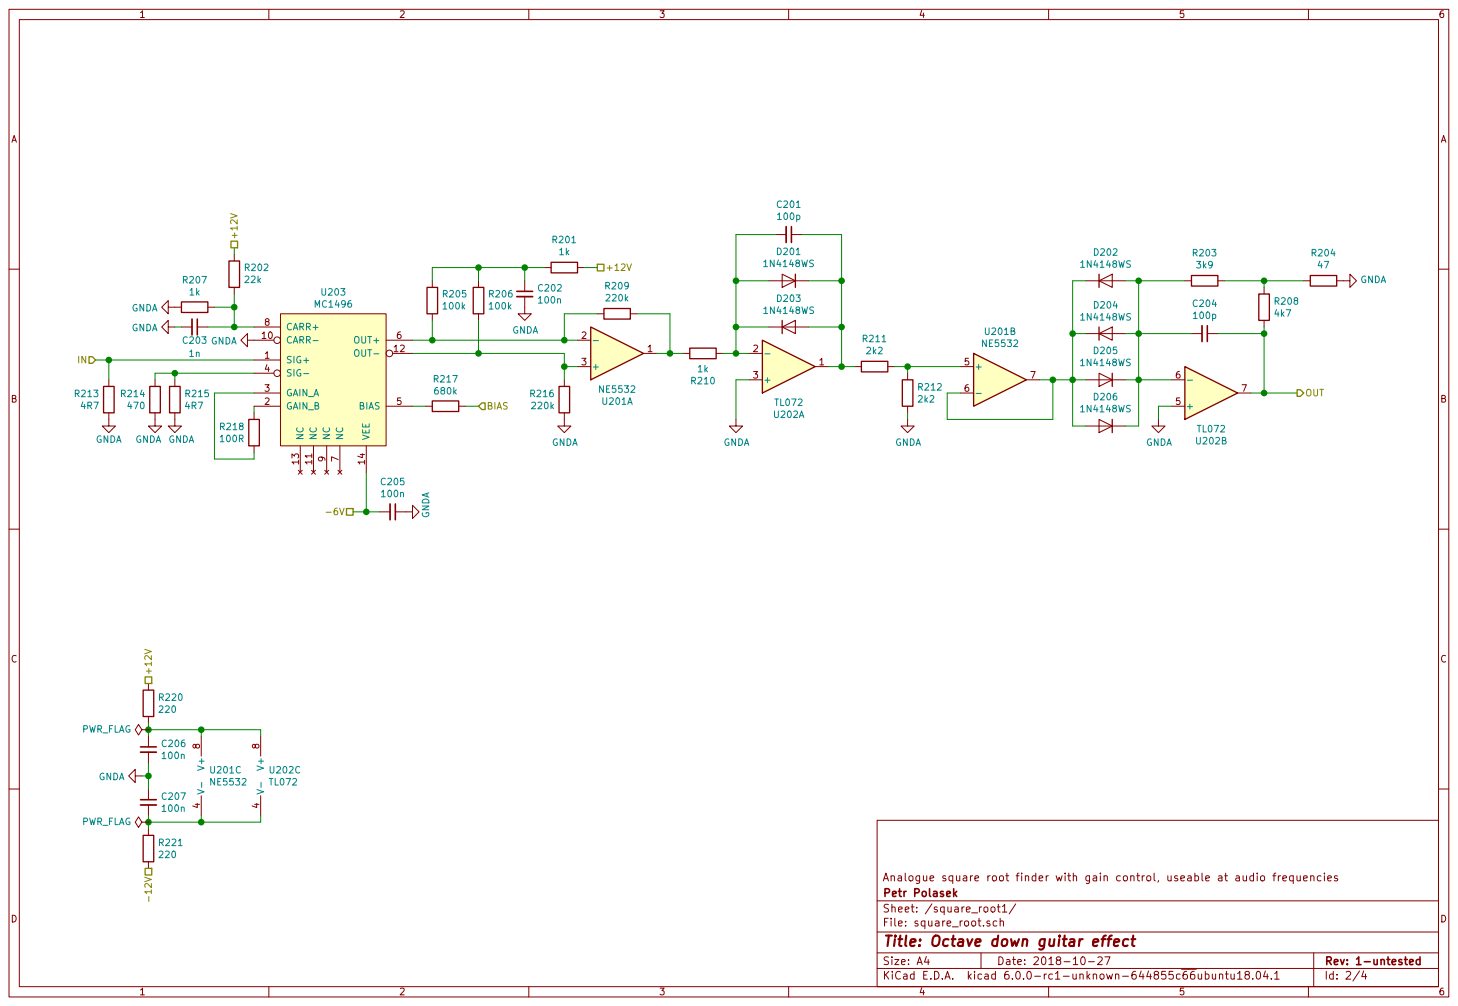
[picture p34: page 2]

Sheet: /square_root1/ Petr Polasek Analogue square root finder with gain control, useable at audio frequencies

File: square_root.sch
Id: 2/4 Title: Octave down guitar effect

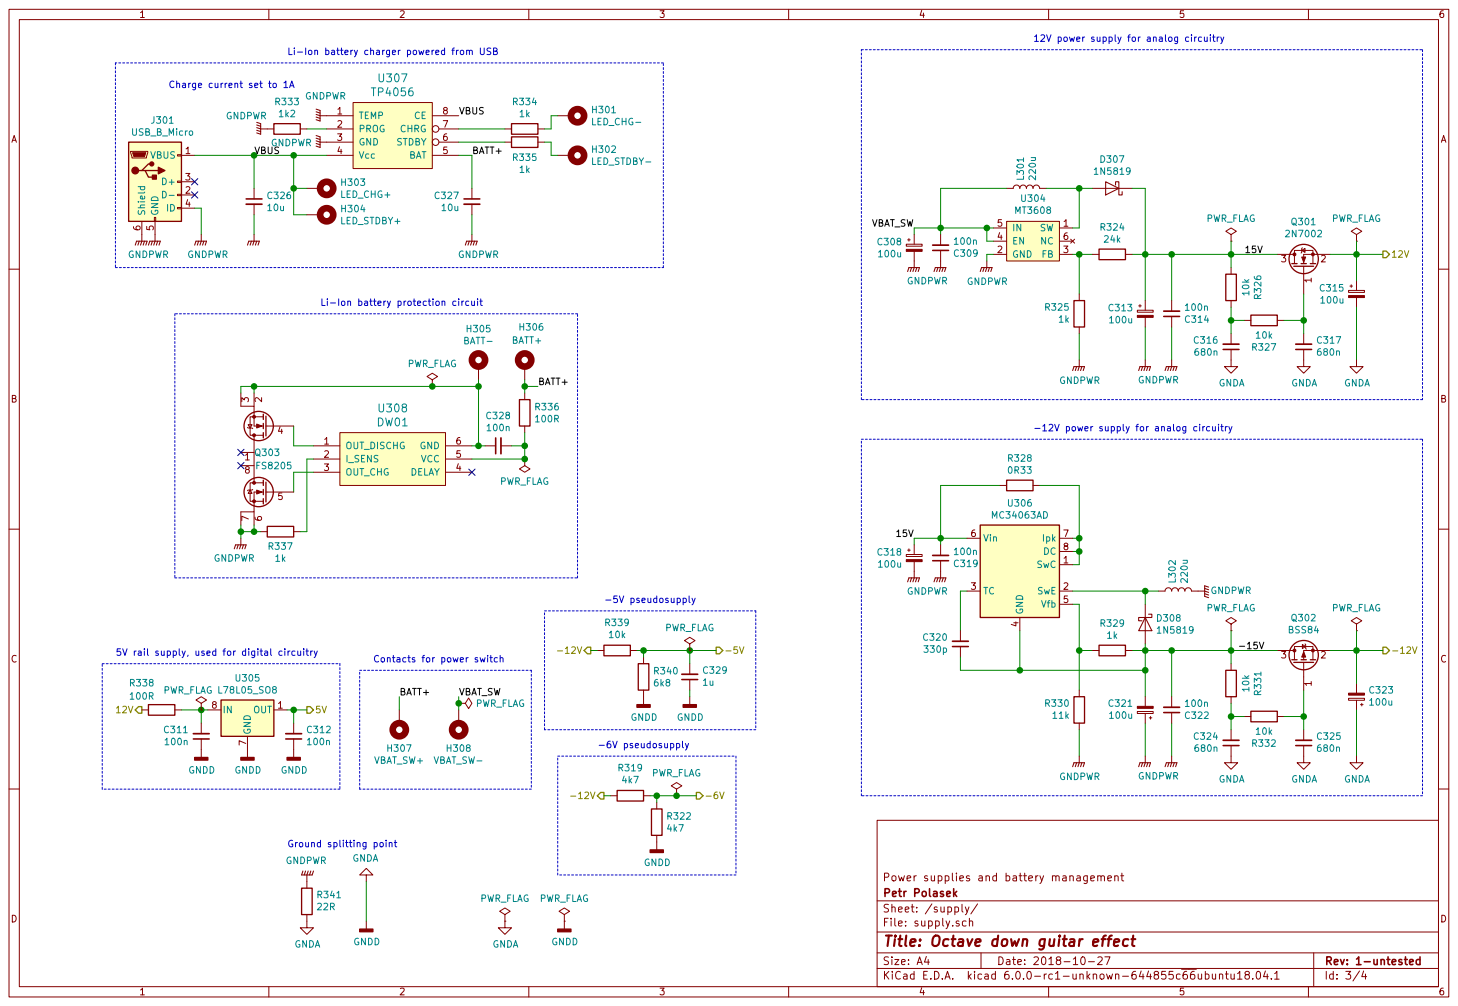
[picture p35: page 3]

Li-Ion battery charger powered from USB

VBUS Charge current set to 1A

Li-Ion battery protection circuit

-12V power supply for analog circuitry

5V rail supply, used for digital circuitry

Sheet: /supply/ Petr Polasek Power supplies and battery management

File: supply.sch
Id: 3/4 Title: Octave down guitar effect

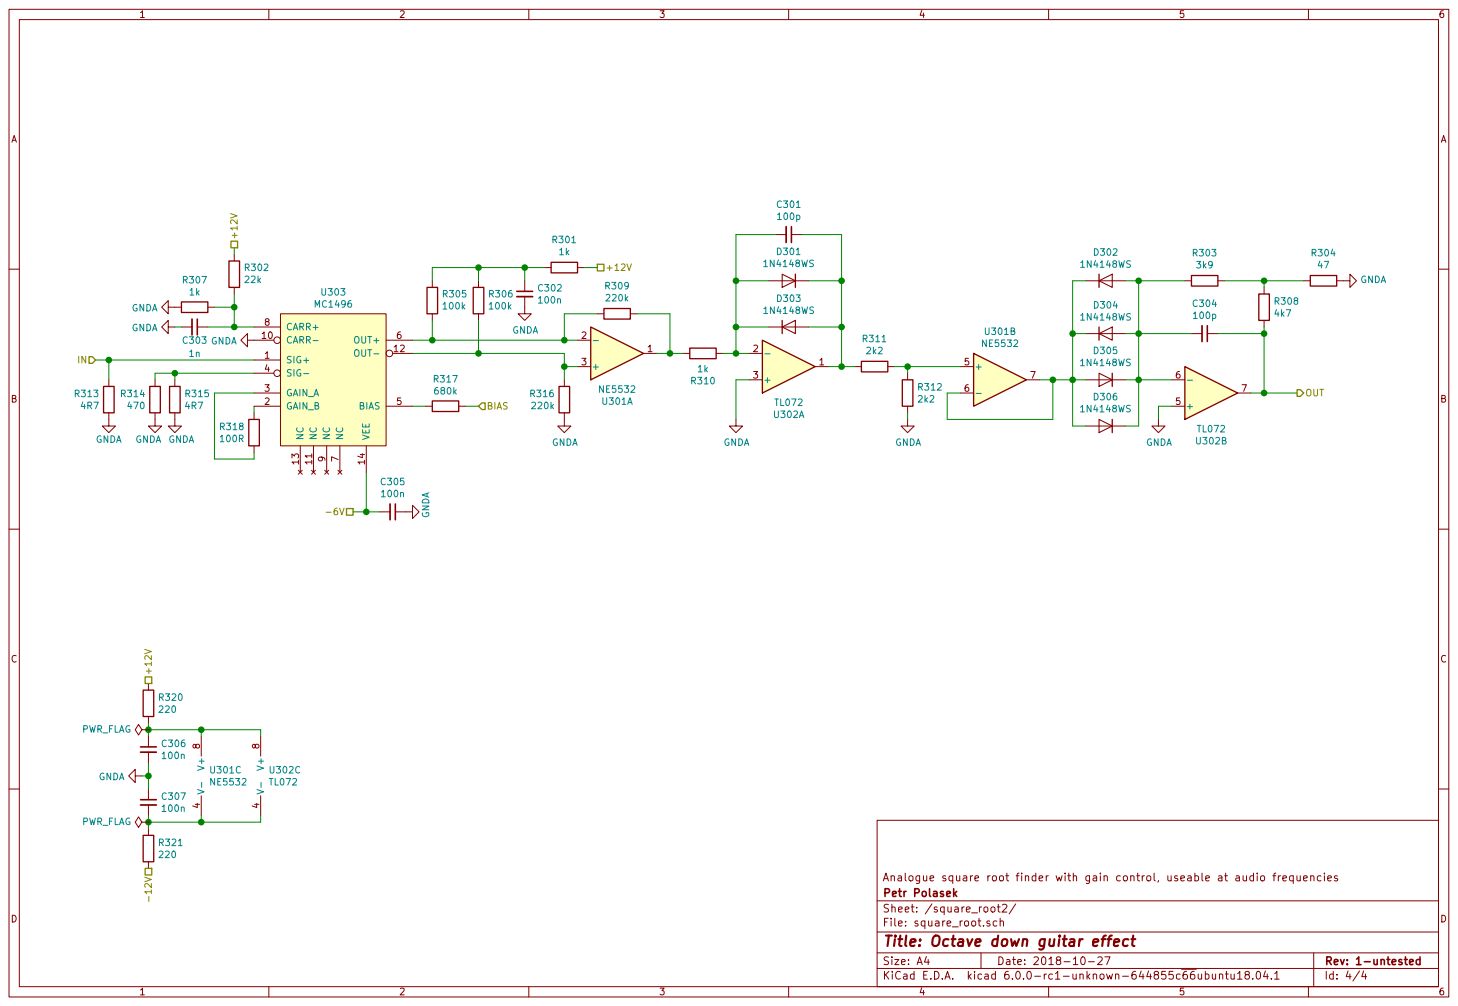
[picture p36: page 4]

Sheet: /square_root2/ Petr Polasek Analogue square root finder with gain control, useable at audio frequencies

File: square_root.sch
Id: 4/4 Title: Octave down guitar effect

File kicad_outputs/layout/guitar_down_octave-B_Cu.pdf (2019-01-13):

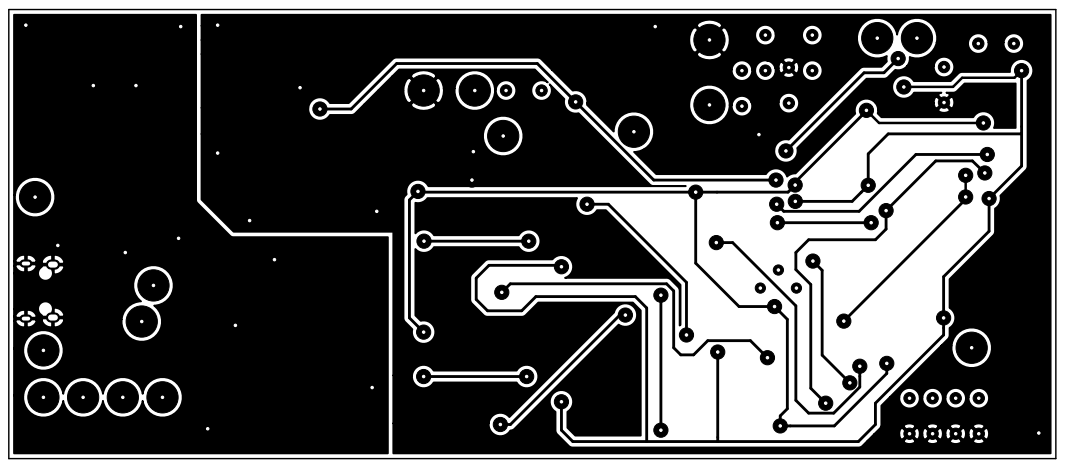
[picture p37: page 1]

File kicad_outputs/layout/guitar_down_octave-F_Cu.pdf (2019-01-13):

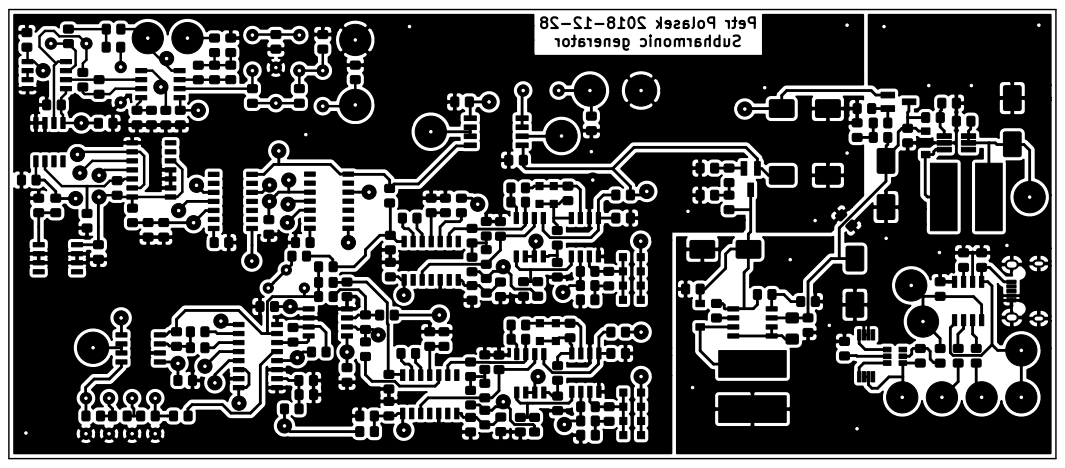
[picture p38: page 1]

Petr Polasek 2018-12-28 Subharmonic generator

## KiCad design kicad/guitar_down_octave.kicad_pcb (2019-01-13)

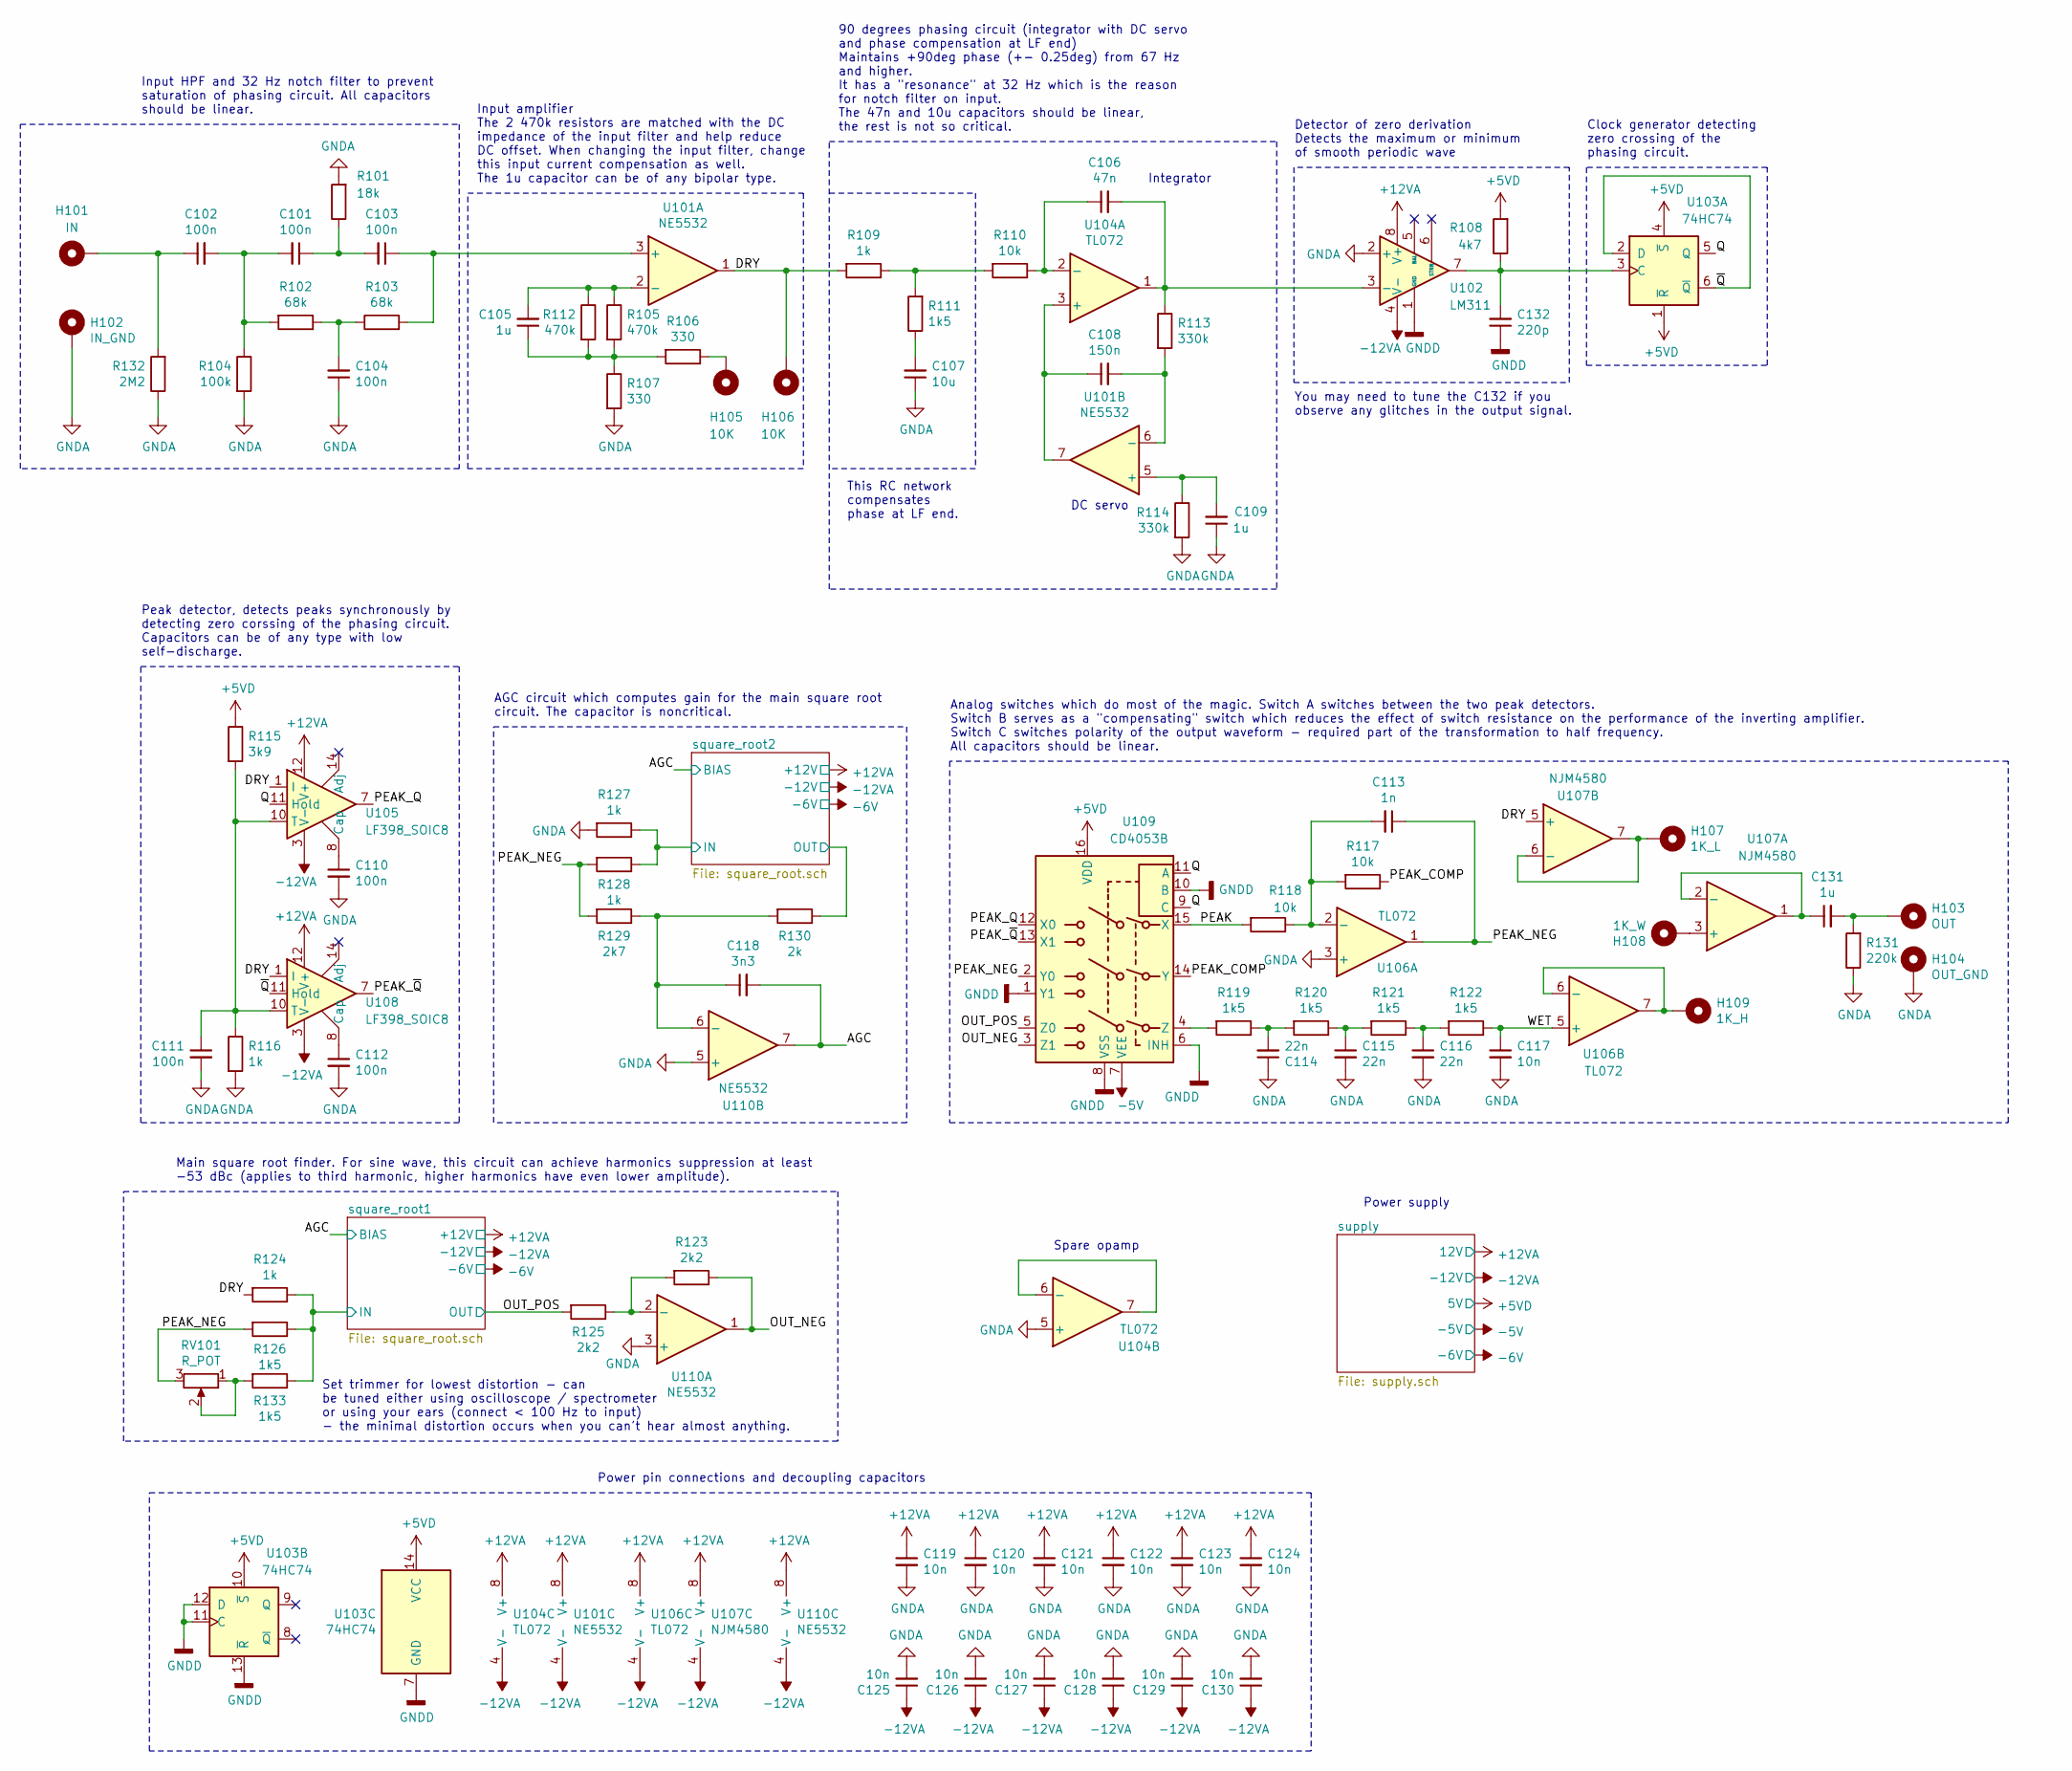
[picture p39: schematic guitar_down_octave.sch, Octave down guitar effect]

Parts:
C101, C102, C103, C104: 100n; C_Rect_L7.2mm_W2.5mm_P5.00mm_FKS2_FKP2_MKS2_MKP2
C105, C109: 1u; C_0805_2012Metric_Pad1.15x1.40mm_HandSolder
C106: 47n; C_Rect_L7.2mm_W2.5mm_P5.00mm_FKS2_FKP2_MKS2_MKP2
C107: 10u; C_Rect_L7.2mm_W7.2mm_P5.00mm_FKS2_FKP2_MKS2_MKP2
C108: 150n; C_0805_2012Metric_Pad1.15x1.40mm_HandSolder
C110, C111, C112: 100n; C_0805_2012Metric_Pad1.15x1.40mm_HandSolder
C113: 1n; C_0805_2012Metric_Pad1.15x1.40mm_HandSolder
C114, C115, C116: 22n; C_Rect_L7.2mm_W2.5mm_P5.00mm_FKS2_FKP2_MKS2_MKP2
C117: 10n; C_Rect_L7.2mm_W2.5mm_P5.00mm_FKS2_FKP2_MKS2_MKP2
C118: 3n3; C_0805_2012Metric_Pad1.15x1.40mm_HandSolder
C119, C120, C121, C122, C123, C124, C125, C126, C127, C128, C129, C130: 10n; C_0805_2012Metric_Pad1.15x1.40mm_HandSolder
C131: 1u; C_Rect_L7.2mm_W7.2mm_P5.00mm_FKS2_FKP2_MKS2_MKP2
C132: 220p; C_0805_2012Metric_Pad1.15x1.40mm_HandSolder
H101: IN; MountingHole_2.2mm_M2_Pad
H102: IN_GND; MountingHole_2.2mm_M2_Pad
H103: OUT; MountingHole_2.2mm_M2_Pad
H104: OUT_GND; MountingHole_2.2mm_M2_Pad
H105, H106: 10K; MountingHole_2.2mm_M2_Pad
H107: 1K_L; MountingHole_2.2mm_M2_Pad
H108: 1K_W; MountingHole_2.2mm_M2_Pad
H109: 1K_H; MountingHole_2.2mm_M2_Pad
R101: 18k; R_0805_2012Metric_Pad1.15x1.40mm_HandSolder
R102, R103: 68k; R_0805_2012Metric_Pad1.15x1.40mm_HandSolder
R104: 100k; R_0805_2012Metric_Pad1.15x1.40mm_HandSolder
R105, R112: 470k; R_0805_2012Metric_Pad1.15x1.40mm_HandSolder
R106, R107: 330; R_0805_2012Metric_Pad1.15x1.40mm_HandSolder
R108: 4k7; R_0805_2012Metric_Pad1.15x1.40mm_HandSolder
R109, R116, R124, R127, R128: 1k; R_0805_2012Metric_Pad1.15x1.40mm_HandSolder
R110, R117, R118: 10k; R_0805_2012Metric_Pad1.15x1.40mm_HandSolder
R111, R119, R120, R121, R122, R126, R133: 1k5; R_0805_2012Metric_Pad1.15x1.40mm_HandSolder
R113, R114: 330k; R_0805_2012Metric_Pad1.15x1.40mm_HandSolder
R115: 3k9; R_0805_2012Metric_Pad1.15x1.40mm_HandSolder
R123, R125: 2k2; R_0805_2012Metric_Pad1.15x1.40mm_HandSolder
R129: 2k7; R_0805_2012Metric_Pad1.15x1.40mm_HandSolder
R130: 2k; R_0805_2012Metric_Pad1.15x1.40mm_HandSolder
R131: 220k; R_0805_2012Metric_Pad1.15x1.40mm_HandSolder
R132: 2M2; R_0805_2012Metric_Pad1.15x1.40mm_HandSolder
RV101: R_POT; Potentiometer_Bourns_3296Y_Vertical
U101, U110: NE5532; SOIC-8_3.9x4.9mm_P1.27mm
U102: LM311; SOIC-8_3.9x4.9mm_P1.27mm
U103: 74HC74; SOIC-14_3.9x8.7mm_P1.27mm
U104, U106: TL072; SOIC-8_3.9x4.9mm_P1.27mm
U105, U108: LF398_SOIC8; SOIC-14_3.9x8.7mm_P1.27mm
U107: NJM4580; SOIJ-8_5.3x5.3mm_P1.27mm
U109: CD4053B; SOIC-16_3.9x9.9mm_P1.27mm

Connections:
+5VD: R108.2, R115.1, U103.1 (~R), U103.4 (~S), U103.10 (~S), U103.14 (VCC), U109.16 (VDD); also elsewhere on the board
+12VA: C119.1, C120.1, C121.1, C122.1, C123.1, C124.1, U101.8 (V+), U102.8 (V+), U104.8 (V+), U105.12 (V+), U106.8 (V+), U107.8 (V+), U108.12 (V+), U110.8 (V+); also elsewhere on the board
-5V: U109.7 (VEE); also elsewhere on the board
-12VA: C125.1, C126.1, C127.1, C128.1, C129.1, C130.1, U101.4 (V-), U102.4 (V-), U104.4 (V-), U105.3 (V-), U106.4 (V-), U107.4 (V-), U108.3 (V-), U110.4 (V-); also elsewhere on the board
/AGC: C118.2, U110.7; also elsewhere on the board
/DRY: H106.1, R109.2, R124.2, U101.1, U105.1 (I), U107.5 (+), U108.1 (I)
/OUT_NEG: R123.1, U109.3 (Z1), U110.1
/OUT_POS: R125.2, U109.5 (Z0); also elsewhere on the board
/PEAK: R118.2, U109.15 (X)
/PEAK_COMP: R117.1, U109.14 (Y)
/PEAK_NEG: C113.1, R126.2, R128.2, R129.2, RV101.3, U106.1, U109.2 (Y0)
/PEAK_Q: U105.7, U109.12 (X0)
/PEAK_~Q: U108.7, U109.13 (X1)
/Q: U103.5 (Q), U105.11 (Hold), U109.9 (C), U109.11 (A)
/WET: C117.1, R122.1, U106.5 (+)
/square_root1/IN: R124.1, R126.1, R133.1; also elsewhere on the board
/square_root2/IN: R127.1, R128.1; also elsewhere on the board
/square_root2/OUT: R130.1; also elsewhere on the board
/~Q: U103.2 (D), U103.6 (~Q), U108.11 (Hold)
GNDA: C104.1, C107.1, C109.1, C110.2, C111.2, C112.2, C114.1, C115.2, C116.2, C117.2, C119.2, C120.2, C121.2, C122.2, C123.2, C124.2, C125.2, C126.2, C127.2, C128.2, C129.2, C130.2, C132.1, H102.1, H104.1, R101.2, R104.2, R107.2, R114.2, R116.2, R127.2, R131.1, R132.1, U102.1 (GND), U102.2 (+), U103.7 (GND), U103.11 (C), U103.12 (D), U103.13 (~R), U104.5 (+), U106.3 (+), U109.1 (Y1), U109.6 (INH), U109.8 (VSS), U109.10 (B), U110.3 (+), U110.5 (+); also elsewhere on the board
unnamed: C101.1, C103.2, R101.1
unnamed: C101.2, C102.2, R102.2, R104.1
unnamed: C102.1, H101.1, R132.2
unnamed: C103.1, R103.2, U101.3 (+)
unnamed: C104.2, R102.1, R103.1
unnamed: C105.1, R105.2, R106.2, R107.1, R112.2
unnamed: C105.2, R105.1, R112.1, U101.2 (-)
unnamed: C106.1, R110.1, U104.2 (-)
unnamed: C106.2, R113.1, U102.3 (-), U104.1
unnamed: C107.2, R111.1
unnamed: C108.1, U101.7, U104.3 (+)
unnamed: C108.2, R113.2, U101.6 (-)
unnamed: C109.2, R114.1, U101.5 (+)
unnamed: C110.1, U105.8 (Cap)
unnamed: C111.1, R115.2, R116.1, U105.10 (T), U108.10 (T)
unnamed: C112.1, U108.8 (Cap)
unnamed: C113.2, R117.2, R118.1, U106.2 (-)
unnamed: C114.2, R119.1, R120.2
unnamed: C115.1, R120.1, R121.2
unnamed: C116.1, R121.1, R122.2
unnamed: C118.1, R129.1, R130.2, U110.6 (-)
unnamed: C131.1, U107.1, U107.2 (-)
unnamed: C131.2, H103.1, R131.2
unnamed: C132.2, R108.1, U102.7, U103.3 (C)
unnamed: H105.1, R106.1
unnamed: H107.1, U107.6 (-), U107.7
unnamed: H108.1, U107.3 (+)
unnamed: H109.1, U106.6 (-), U106.7
unnamed: R109.1, R110.2, R111.2
unnamed: R119.2, U109.4 (Z)
unnamed: R123.2, R125.1, U110.2 (-)
unnamed: R133.2, RV101.1, RV101.2
unnamed: U104.6 (-), U104.7

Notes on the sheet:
Input HPF and 32 Hz notch filter to prevent saturation of phasing circuit. All capacitors should be linear.
90 degrees phasing circuit (integrator with DC servo and phase compensation at LF end) Maintains +90deg phase (+- 0.25deg) from 67 Hz and higher. It has a "resonance" at 32 Hz which is the reason for notch filter on input. The 47n and 10u capacitors should be linear, the rest is not so critical.
Detector of zero derivation Detects the maximum or minimum of smooth periodic wave
Input amplifier The 2 470k resistors are matched with the DC impedance of the input filter and help reduce DC offset. When changing the input filter, change this input current compensation as well. The 1u capacitor can be of any bipolar type.
This RC network compensates phase at LF end.
Integrator
DC servo
Peak detector, detects peaks synchronously by detecting zero corssing of the phasing circuit. Capacitors can be of any type with low self-discharge.
Clock generator detecting zero crossing of the phasing circuit.
Analog switches which do most of the magic. Switch A switches between the two peak detectors. Switch B serves as a "compensating" switch which reduces the effect of switch resistance on the performance of the inverting amplifier. Switch C switches polarity of the output waveform - required part of 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
AGC circuit which computes gain for the main square root circuit. The capacitor is noncritical.
Main square root finder. For sine wave, this circuit can achieve harmonics suppression at least -53 dBc (applies to third harmonic, higher harmonics have even lower amplitude).
Spare opamp
Power pin connections and decoupling capacitors
Power supply
Set trimmer for lowest distortion - can be tuned either using oscilloscope / spectrometer or using your ears (connect < 100 Hz to input) - the minimal distortion occurs when you can't hear almost anything.
You may need to tune the C132 if you observe any glitches in the output signal.

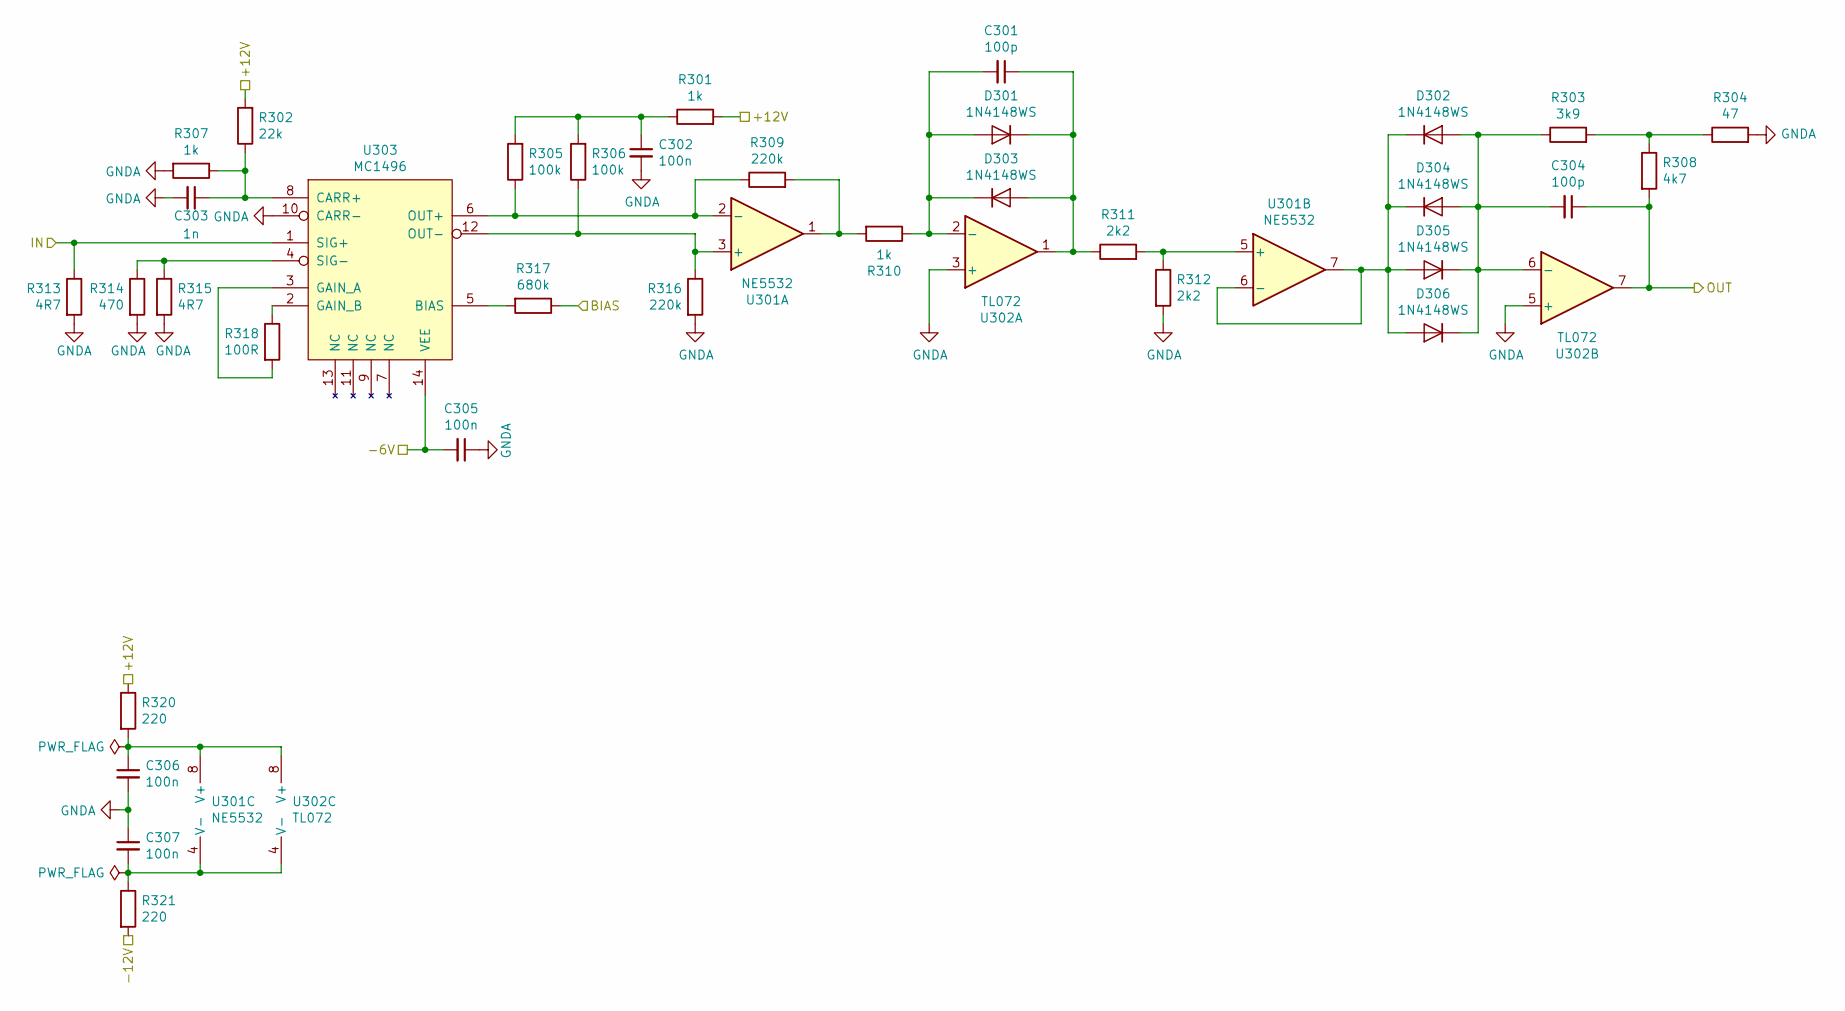
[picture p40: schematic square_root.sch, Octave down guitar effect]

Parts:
C201, C204: 100p; C_0805_2012Metric_Pad1.15x1.40mm_HandSolder
C202, C205, C206, C207: 100n; C_0805_2012Metric_Pad1.15x1.40mm_HandSolder
C203: 1n; C_0805_2012Metric_Pad1.15x1.40mm_HandSolder
D201, D202, D203, D204, D205, D206: 1N4148WS; D_SOD-323_HandSoldering
R201, R207, R210: 1k; R_0805_2012Metric_Pad1.15x1.40mm_HandSolder
R202: 22k; R_0805_2012Metric_Pad1.15x1.40mm_HandSolder
R203: 3k9; R_0805_2012Metric_Pad1.15x1.40mm_HandSolder
R204: 47; R_0805_2012Metric_Pad1.15x1.40mm_HandSolder
R205, R206: 100k; R_0805_2012Metric_Pad1.15x1.40mm_HandSolder
R208: 4k7; R_0805_2012Metric_Pad1.15x1.40mm_HandSolder
R209, R216: 220k; R_0805_2012Metric_Pad1.15x1.40mm_HandSolder
R211, R212: 2k2; R_0805_2012Metric_Pad1.15x1.40mm_HandSolder
R213, R215: 4R7; R_0805_2012Metric_Pad1.15x1.40mm_HandSolder
R214: 470; R_0805_2012Metric_Pad1.15x1.40mm_HandSolder
R217: 680k; R_0805_2012Metric_Pad1.15x1.40mm_HandSolder
R218: 100R; R_0805_2012Metric_Pad1.15x1.40mm_HandSolder
R220, R221: 220; R_0805_2012Metric_Pad1.15x1.40mm_HandSolder
U201: NE5532; SOIC-8_3.9x4.9mm_P1.27mm
U202: TL072; SOIC-8_3.9x4.9mm_P1.27mm
U203: MC1496; SOIC-14_3.9x8.7mm_P1.27mm

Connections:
+12VA: R201.2, R202.2, R220.1; also elsewhere on the board
-6V: C205.2, U203.14 (VEE); also elsewhere on the board
-12VA: R221.2; also elsewhere on the board
/AGC: R217.1; also elsewhere on the board
/OUT_POS: C204.1, R208.2, U202.7; also elsewhere on the board
/square_root1/IN: R213.1, U203.1 (SIG+); also elsewhere on the board
GNDA: C202.2, C203.2, C205.1, C206.2, C207.1, R204.2, R207.2, R212.2, R213.2, R214.2, R215.2, R216.2, U202.3 (+), U202.5 (+), U203.10 (CARR-); also elsewhere on the board
unnamed: C201.1, D201.1 (K), D203.2 (A), R211.1, U202.1
unnamed: C201.2, D201.2 (A), D203.1 (K), R210.1, U202.2 (-)
unnamed: C202.1, R201.1, R205.2, R206.2
unnamed: C203.1, R202.1, R207.1, U203.8 (CARR+)
unnamed: C204.2, D202.2 (A), D204.2 (A), D205.1 (K), D206.1 (K), R203.1, U202.6 (-)
unnamed: C206.1, R220.2, U201.8 (V+), U202.8 (V+)
unnamed: C207.2, R221.1, U201.4 (V-), U202.4 (V-)
unnamed: D202.1 (K), D204.1 (K), D205.2 (A), D206.2 (A), U201.6 (-), U201.7
unnamed: R203.2, R204.1, R208.1
unnamed: R205.1, R209.1, U201.2 (-), U203.6 (OUT+)
unnamed: R206.1, R216.1, U201.3 (+), U203.12 (OUT-)
unnamed: R209.2, R210.2, U201.1
unnamed: R211.2, R212.1, U201.5 (+)
unnamed: R214.1, R215.1, U203.4 (SIG-)
unnamed: R217.2, U203.5 (BIAS)
unnamed: R218.1, U203.2 (GAIN_B)
unnamed: R218.2, U203.3 (GAIN_A)

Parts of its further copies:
C301, C304: 100p; C_0805_2012Metric_Pad1.15x1.40mm_HandSolder
C302, C305, C306, C307: 100n; C_0805_2012Metric_Pad1.15x1.40mm_HandSolder
C303: 1n; C_0805_2012Metric_Pad1.15x1.40mm_HandSolder
D301, D302, D303, D304, D305, D306: 1N4148WS; D_SOD-323_HandSoldering
R301, R307, R310: 1k; R_0805_2012Metric_Pad1.15x1.40mm_HandSolder
R302: 22k; R_0805_2012Metric_Pad1.15x1.40mm_HandSolder
R303: 3k9; R_0805_2012Metric_Pad1.15x1.40mm_HandSolder
R304: 47; R_0805_2012Metric_Pad1.15x1.40mm_HandSolder
R305, R306: 100k; R_0805_2012Metric_Pad1.15x1.40mm_HandSolder
R308: 4k7; R_0805_2012Metric_Pad1.15x1.40mm_HandSolder
R309, R316: 220k; R_0805_2012Metric_Pad1.15x1.40mm_HandSolder
R311, R312: 2k2; R_0805_2012Metric_Pad1.15x1.40mm_HandSolder
R313, R315: 4R7; R_0805_2012Metric_Pad1.15x1.40mm_HandSolder
R314: 470; R_0805_2012Metric_Pad1.15x1.40mm_HandSolder
R317: 680k; R_0805_2012Metric_Pad1.15x1.40mm_HandSolder
R318: 100R; R_0805_2012Metric_Pad1.15x1.40mm_HandSolder
R320, R321: 220; R_0805_2012Metric_Pad1.15x1.40mm_HandSolder
U301: NE5532; SOIC-8_3.9x4.9mm_P1.27mm
U302: TL072; SOIC-8_3.9x4.9mm_P1.27mm
U303: MC1496; SOIC-14_3.9x8.7mm_P1.27mm

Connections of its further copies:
+12VA: R301.2, R302.2, R320.1; also elsewhere on the board
-6V: C305.2, U303.14 (VEE); also elsewhere on the board
-12VA: R321.2; also elsewhere on the board
/AGC: R317.1; also elsewhere on the board
/square_root2/IN: R313.1, U303.1 (SIG+); also elsewhere on the board
/square_root2/OUT: C304.1, R308.2, U302.7; also elsewhere on the board
GNDA: C302.2, C303.2, C305.1, C306.2, C307.1, R304.2, R307.2, R312.2, R313.2, R314.2, R315.2, R316.2, U302.3 (+), U302.5 (+), U303.10 (CARR-); also elsewhere on the board
unnamed: C301.1, D301.1 (K), D303.2 (A), R311.1, U302.1
unnamed: C301.2, D301.2 (A), D303.1 (K), R310.1, U302.2 (-)
unnamed: C302.1, R301.1, R305.2, R306.2
unnamed: C303.1, R302.1, R307.1, U303.8 (CARR+)
unnamed: C304.2, D302.2 (A), D304.2 (A), D305.1 (K), D306.1 (K), R303.1, U302.6 (-)
unnamed: C306.1, R320.2, U301.8 (V+), U302.8 (V+)
unnamed: C307.2, R321.1, U301.4 (V-), U302.4 (V-)
unnamed: D302.1 (K), D304.1 (K), D305.2 (A), D306.2 (A), U301.6 (-), U301.7
unnamed: R303.2, R304.1, R308.1
unnamed: R305.1, R309.1, U301.2 (-), U303.6 (OUT+)
unnamed: R306.1, R316.1, U301.3 (+), U303.12 (OUT-)
unnamed: R309.2, R310.2, U301.1
unnamed: R311.2, R312.1, U301.5 (+)
unnamed: R314.1, R315.1, U303.4 (SIG-)
unnamed: R317.2, U303.5 (BIAS)
unnamed: R318.1, U303.2 (GAIN_B)
unnamed: R318.2, U303.3 (GAIN_A)

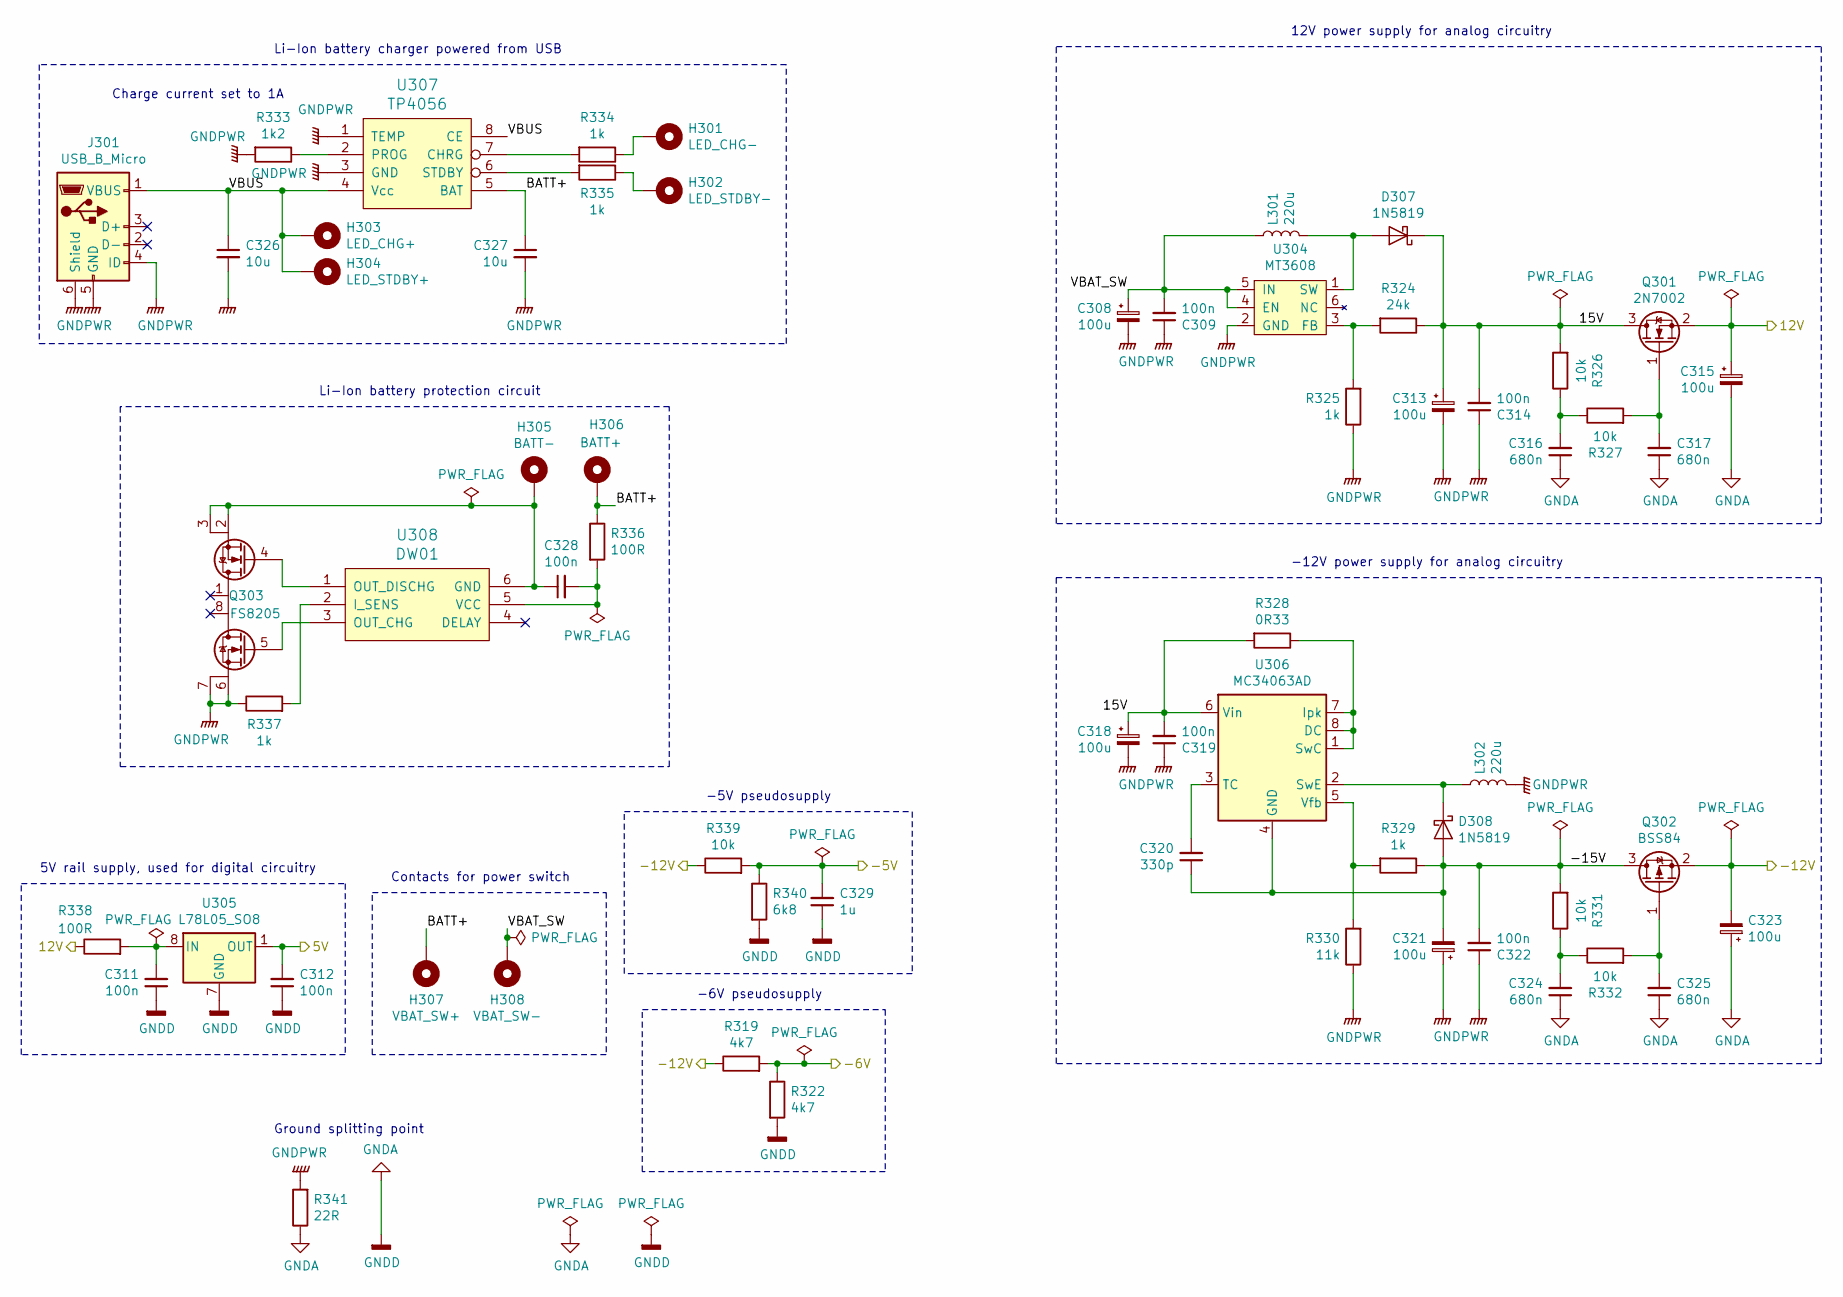
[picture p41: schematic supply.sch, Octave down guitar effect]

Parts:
C308, C313, C315, C318, C321, C323: 100u; CP_Elec_8x10
C309, C311, C312, C314, C319, C322, C328: 100n; C_0805_2012Metric_Pad1.15x1.40mm_HandSolder
C316, C317, C324, C325: 680n; C_0805_2012Metric_Pad1.15x1.40mm_HandSolder
C320: 330p; C_0805_2012Metric_Pad1.15x1.40mm_HandSolder
C326, C327: 10u; C_0805_2012Metric_Pad1.15x1.40mm_HandSolder
C329: 1u; C_0805_2012Metric_Pad1.15x1.40mm_HandSolder
D307, D308: 1N5819; D_SOD-123
H301: LED_CHG-; MountingHole_2.2mm_M2_Pad
H302: LED_STDBY-; MountingHole_2.2mm_M2_Pad
H303: LED_CHG+; MountingHole_2.2mm_M2_Pad
H304: LED_STDBY+; MountingHole_2.2mm_M2_Pad
H305: BATT-; MountingHole_2.2mm_M2_Pad
H306: BATT+; MountingHole_2.2mm_M2_Pad
H307: VBAT_SW+; MountingHole_2.2mm_M2_Pad
H308: VBAT_SW-; MountingHole_2.2mm_M2_Pad
J301: USB_B_Micro; USB_Micro-B_Wuerth_629105150521
L301, L302: 220u; L_Wuerth_WE-PD2-Typ-XL
Q301: 2N7002; SOT-23_Handsoldering
Q302: BSS84; SOT-23_Handsoldering
Q303: FS8205; TSSOP-8_4.4x3mm_P0.65mm
R319, R322: 4k7; R_0805_2012Metric_Pad1.15x1.40mm_HandSolder
R324: 24k; R_0805_2012Metric_Pad1.15x1.40mm_HandSolder
R325, R329, R334, R335, R337: 1k; R_0805_2012Metric_Pad1.15x1.40mm_HandSolder
R326, R327, R331, R332, R339: 10k; R_0805_2012Metric_Pad1.15x1.40mm_HandSolder
R328: 0R33; R_1206_3216Metric_Pad1.42x1.75mm_HandSolder
R330: 11k; R_0805_2012Metric_Pad1.15x1.40mm_HandSolder
R333: 1k2; R_0805_2012Metric_Pad1.15x1.40mm_HandSolder
R336, R338: 100R; R_0805_2012Metric_Pad1.15x1.40mm_HandSolder
R340: 6k8; R_0805_2012Metric_Pad1.15x1.40mm_HandSolder
R341: 22R; R_0805_2012Metric_Pad1.15x1.40mm_HandSolder
U304: MT3608; TSOT-23-6_HandSoldering
U305: L78L05_SO8; SOIC-8_3.9x4.9mm_P1.27mm
U306: MC34063AD; SOIC-8_3.9x4.9mm_P1.27mm
U307: TP4056; SOIC-8_3.9x4.9mm_P1.27mm
U308: DW01; SOT-23-6

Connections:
+5VD: C312.2, U305.1 (OUT); also elsewhere on the board
+12VA: C315.1, Q301.2 (S), R338.1; also elsewhere on the board
-5V: C329.2, R339.2, R340.1; also elsewhere on the board
-6V: R319.2, R322.1; also elsewhere on the board
-12VA: C323.2, Q302.2 (S), R319.1, R339.1; also elsewhere on the board
/supply/15V: C313.1, C314.2, C318.1, C319.2, D307.1 (K), Q301.3 (D), R324.1, R326.2, R328.2, U306.6 (Vin)
/supply/-15V: C320.1, C321.2, C322.2, D308.2 (A), Q302.3 (D), R329.1, R331.2, U306.4 (GND)
/supply/BATT+: C327.1, H306.1, H307.1, R336.1, U307.5 (BAT)
/supply/VBAT_SW: C308.1, C309.2, H308.1, L301.1, U304.4 (EN), U304.5 (IN)
/supply/VBUS: C326.1, H303.1, H304.1, J301.1 (VBUS), U307.4 (Vcc), U307.8 (CE)
GNDA: C311.1, C312.1, C315.2, C316.1, C317.1, C323.1, C324.1, C325.1, C329.1, R322.2, R340.2, R341.1, U305.2 (GND), U305.3 (GND), U305.6 (GND), U305.7 (GND); also elsewhere on the board
GNDPWR: C308.2, C309.1, C313.2, C314.1, C318.2, C319.1, C321.1, C322.1, C326.2, C327.2, J301.4 (ID), J301.5 (GND), J301.6 (Shield), L302.2, Q303.6 (S2), Q303.7 (S2), R325.1, R330.1, R333.2, R337.1, R341.2, U304.2 (GND), U307.1 (TEMP), U307.3 (GND)
unnamed: C311.2, R338.2, U305.8 (IN)
unnamed: C316.2, R326.1, R327.1
unnamed: C317.2, Q301.1 (G), R327.2
unnamed: C320.2, U306.3 (TC)
unnamed: C324.2, R331.1, R332.1
unnamed: C325.2, Q302.1 (G), R332.2
unnamed: C328.1, H305.1, Q303.2 (S1), Q303.3 (S1), U308.6 (GND)
unnamed: C328.2, R336.2, U308.5 (VCC)
unnamed: D307.2 (A), L301.2, U304.1 (SW)
unnamed: D308.1 (K), L302.1, U306.2 (SwE)
unnamed: H301.1, R334.1
unnamed: H302.1, R335.1
unnamed: Q303.4 (G1), U308.1 (OUT_DISCHG)
unnamed: Q303.5 (G2), U308.3 (OUT_CHG)
unnamed: R324.2, R325.2, U304.3 (FB)
unnamed: R328.1, U306.1 (SwC), U306.7 (Ipk), U306.8 (DC)
unnamed: R329.2, R330.2, U306.5 (Vfb)
unnamed: R333.1, U307.2 (PROG)
unnamed: R334.2, U307.7 (CHRG)
unnamed: R335.2, U307.6 (STDBY)
unnamed: R337.2, U308.2 (I_SENS)

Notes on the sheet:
Charge current set to 1A
Li-Ion battery charger powered from USB
Li-Ion battery protection circuit
5V rail supply, used for digital circuitry
-12V power supply for analog circuitry
12V power supply for analog circuitry
Contacts for power switch
-5V pseudosupply
Ground splitting point
-6V pseudosupply

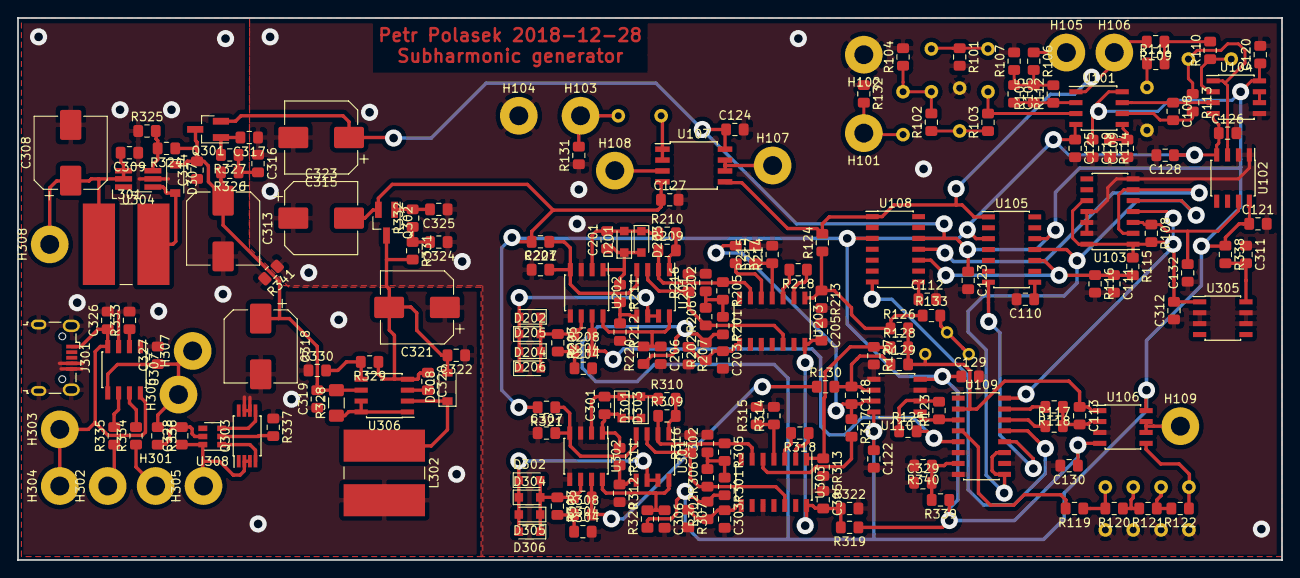
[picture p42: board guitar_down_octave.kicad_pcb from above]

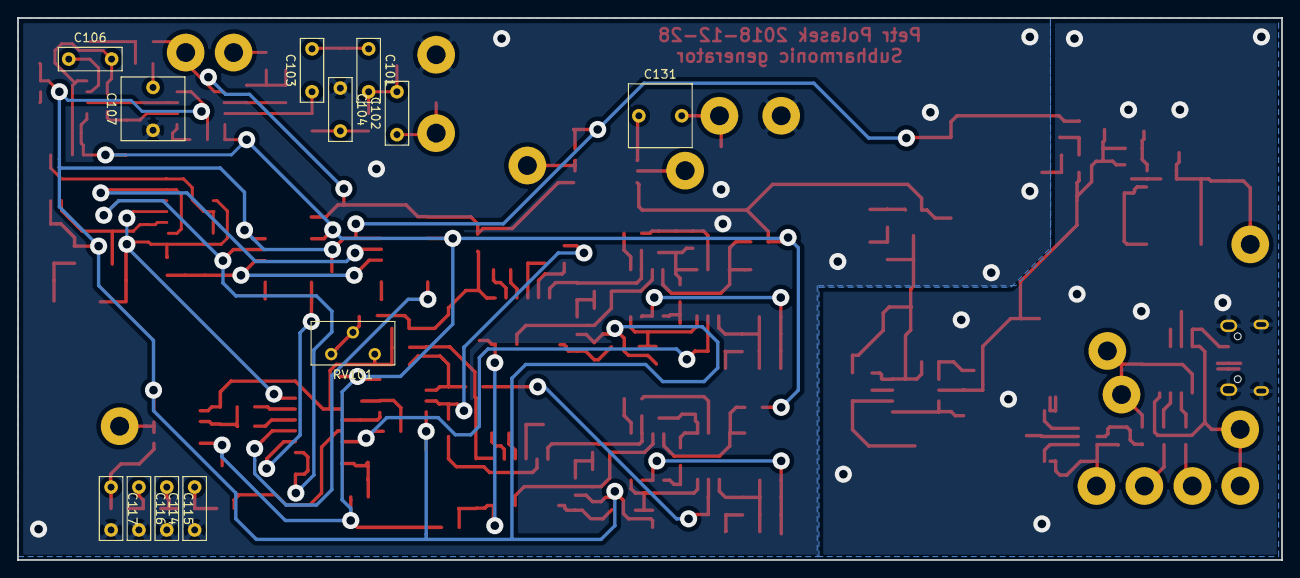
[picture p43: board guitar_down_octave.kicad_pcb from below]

Board: 2 copper layers, 147.4 x 63.2 mm, 219 parts (12 on the bottom side), 115 nets.
